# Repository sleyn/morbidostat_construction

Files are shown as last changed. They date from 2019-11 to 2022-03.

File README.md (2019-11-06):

# Morbidostat construction
Building Osterman Lab implementation of morbidostat.

Detailed description of morbidostat components:
1. [Hardware](./Hardware.md)
2. [Software](./Software.md)
3. [Standard operating procedures](./SOP.md)
4. [Spreadsheet with componets specifications](./aux_files/components.xlsx)

## General principles
We constructed our morbidostat based on the same principles that were described in the Toprak et al. paper <a href='#link1'>[1]</a>. In short:  
1)	Optical density of the culture in the reactor is measured every fixed time.  
2)	At the time when the software should initiate dilution the current optical density (OD1) is compared with two values: Upper threshold (UT) and previous optical density (OD0).  
3)	If OD1 ≥ UT and OD1-OD0 ≥ 0 the dilution is made with the drug media.  
4)	Else the fresh media is added

We introduced a new feature - **the lower threshold (LT)**. If OD1 < LT then morbidostat dilutes the culture in the reactor once in hour with the fresh media. LT used:  
1. to allow to start the run on the very low initial OD and to enable active dilution at the same OD for all reactors;  
2. to prevent wash out of the culture during the run.

Dilution by fresh media below the LT once per hour helps to avoid reactor drying during long “sleeping” phase and to decrease residual drug concentration without wash out of the culture.

## Assembled Morbidostat

Morbidostat was assembled in the custom-made box equipped with thermostat, web-camera and air pump.

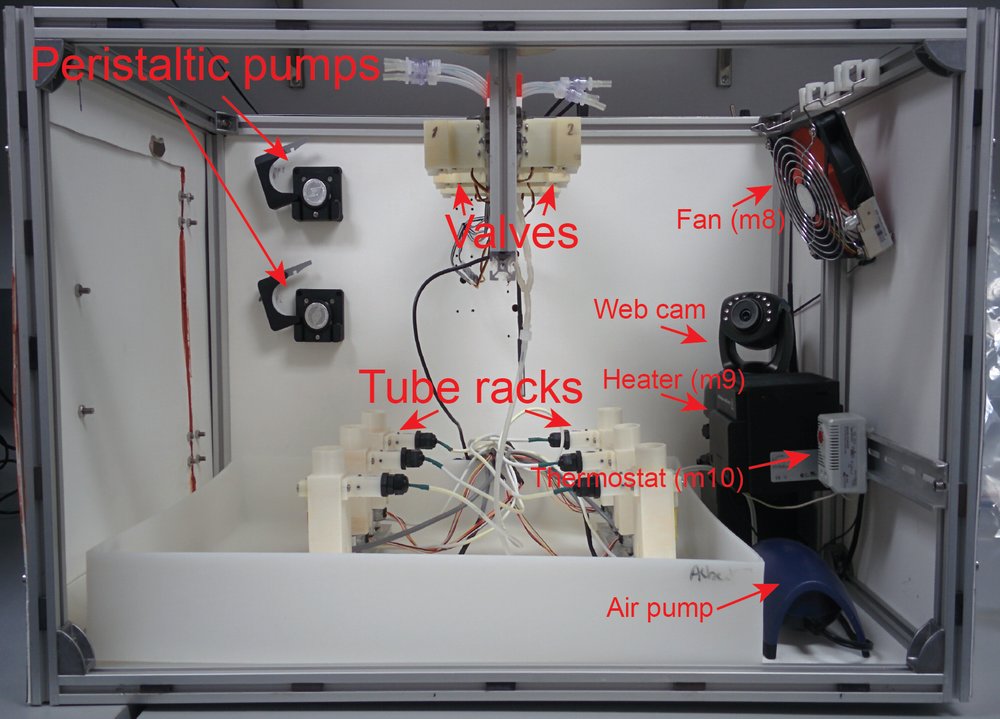
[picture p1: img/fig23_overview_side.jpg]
Morbidostat side
<br>
**Figure 1.** Morbidostat. Side view.

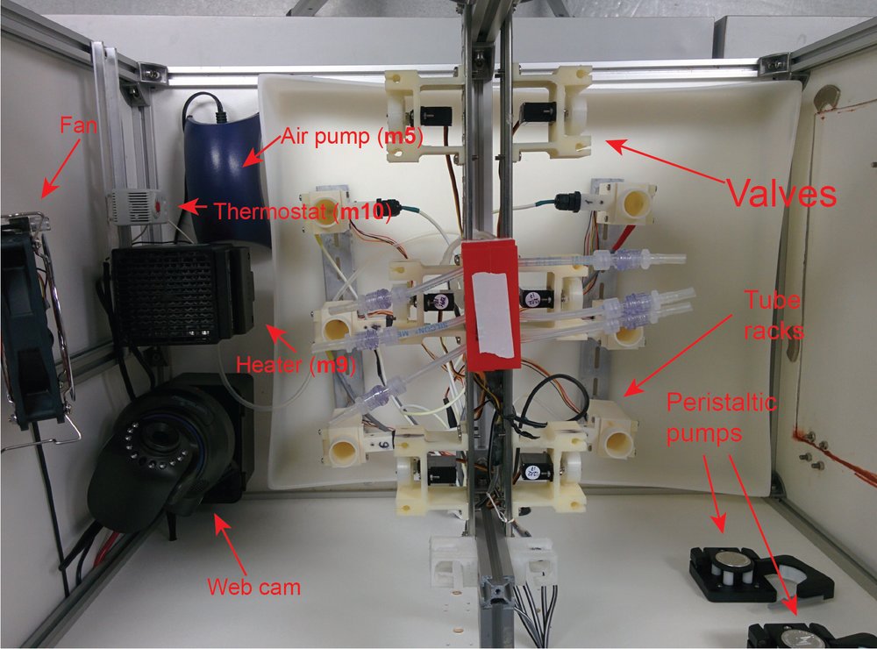
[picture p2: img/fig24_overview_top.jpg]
Morbidostat top
<br>
**Figure 2.** Morbidostat. View form above.

## References

[1]: Toprak E, Veres A, Yildiz S, Pedraza JM, Chait R, Paulsson J, Kishony R: Building a morbidostat: an automated continuous-culture device for studying bacterial drug resistance under dynamically sustained drug inhibition. Nat Protoc 2013, 8(3):555-567.  
DOI: [10.1038/nprot.nprot.2013.021](http://dx.doi.org/10.1038/nprot.nprot.2013.021)

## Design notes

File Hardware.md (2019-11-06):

#### [<Back](./README.md)

# Morbidostat hardware components

- [1. Fluidics](#p1)
  * [1.1 Detailed tubing description](#p11)
    * [1.1.1	Media bottles with the connection lines](#p11)
    * [1.1.2 Distribution lines](#p112)
    * [1.1.3 Reactor tubing and reactor](#p113)
    * [1.1.4 Waste lines](#p114)
- [2. Mechanics](#p2)
  * [2.1 Detailed mechanical parts description](#p21)
- [3. Optics](#p3)
  * [3.1 Detailed optics description](#p31)
- [4. Electrical schemes](#p4)
- [5. 3D-printing](#p5)
  * [5.1 STL files](#p51)
- [6. Assembled morbidostat](#p6)

## 1. Fluidics
Morbidostat has five types of the tubing parts:
1.	**Media bottles with the connection lines** – store drug-containing and fresh media and connect bottles to the pumps.
2.	**Distribution lines** – distribute media among six reactors. Distribution is controlled by peristaltic pumps and valves. Valve simultaneously close or open both tubes containing fresh and drug media. One valve works for one reactor – six valves total. For the dilution the reactors valve opens and one of the pump controlling fresh or drug-containing media start operating.
3.	**Reactor input tubing** – aeration and dilution media introduction. We united air and media input tubings to allow air to make a dry space between fresh media and culturing media. It was made to avoid backflow of the cultured bacteria to the sterile media bottles. This tubing connected to the needle that has its blunt end in the culturing media to introduce bubbling that increases an aeration.
4.	**Reactor** – glass culture tube. Has three ports: input, sampling and waste. In all three ports blunt needles are inserted into the septa. OD in the reactor is measured by laser that is located in the tube rack. To introduce mixing a small stirring motor with the magnets rotates the bar in the tube.
5.	**Waste line** – open line which leads to the bottle with sodium azide. Waste is removed from the reactor by the air pressure. The line has a check valve that prevents backflow of the waste media from the tubing to the reactor.

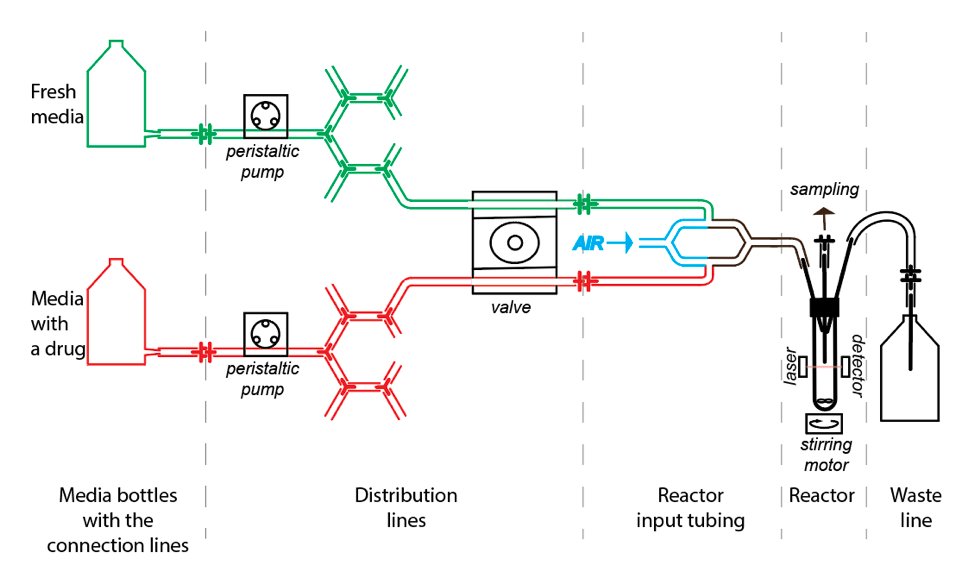
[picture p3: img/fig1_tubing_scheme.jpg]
General scheme of the morbidostat tubing
<br>
**Figure 1.** General scheme of the morbidostat tubing. Tubing colors:  
  *green* – fresh media,  *red* – drug-containing media,  *blue* – air.

### 1.1 Detailed tubing description
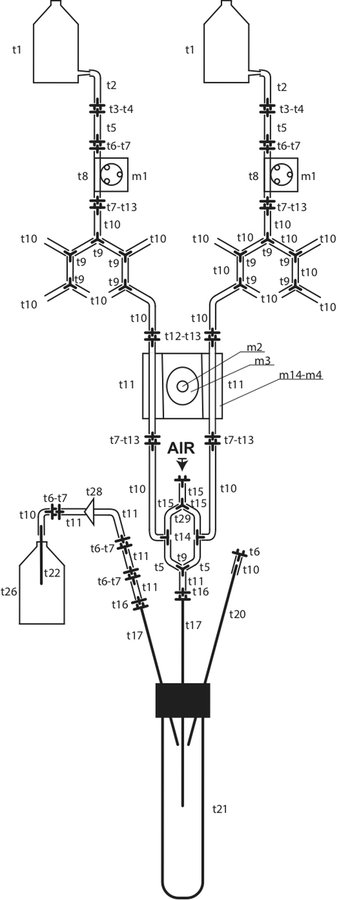
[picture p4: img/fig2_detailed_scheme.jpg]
Detailed tubing scheme
<br>
**Figure 3.** Detailed tubing scheme.  
The part numbers are indicated according the supplementary parts specification table.

#### 1.1.1	Media bottles with the connection lines
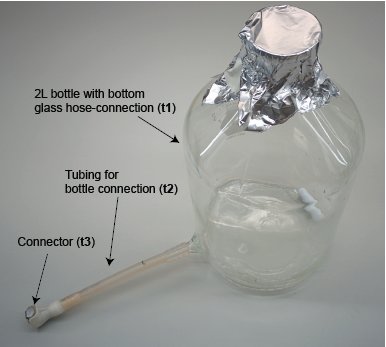
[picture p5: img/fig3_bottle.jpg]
Media bottle
<br>
**Figure 3.** Media bottle with tubing.  
Alpha-numeric parts numbers in parenthesis here and further identify components in the parts specification table.

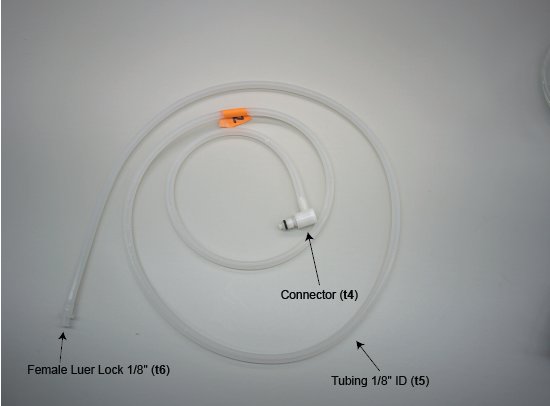
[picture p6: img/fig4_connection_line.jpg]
<br>
**Figure 4.** Connection line.

#### 1.1.2 Distribution lines

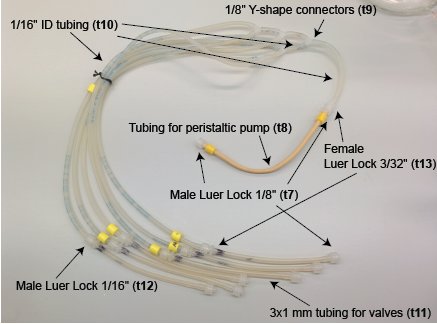
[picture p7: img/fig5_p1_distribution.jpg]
<br>
**Figure 5.** Fresh media distribution line.

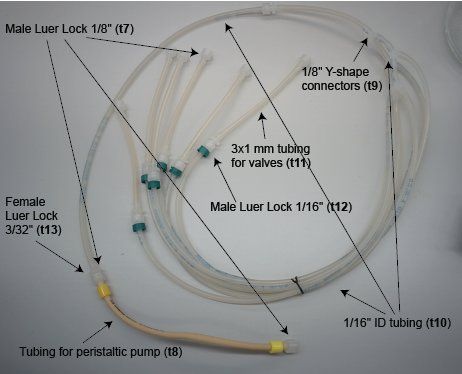
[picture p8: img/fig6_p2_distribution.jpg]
<br>
**Figure 6.** Drug-containing media distribution line. Tubing scheme is the same as for the line on figure 4 but has an additional elongation segment.

#### 1.1.3 Reactor tubing and reactor

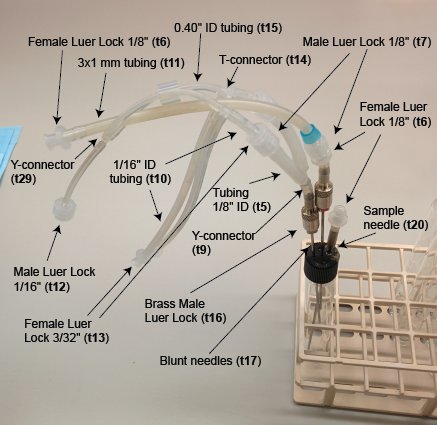
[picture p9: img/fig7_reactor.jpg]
Reactor
<br>
**Figure 7.** Reactor and reactor tubing.

#### 1.1.4 Waste lines

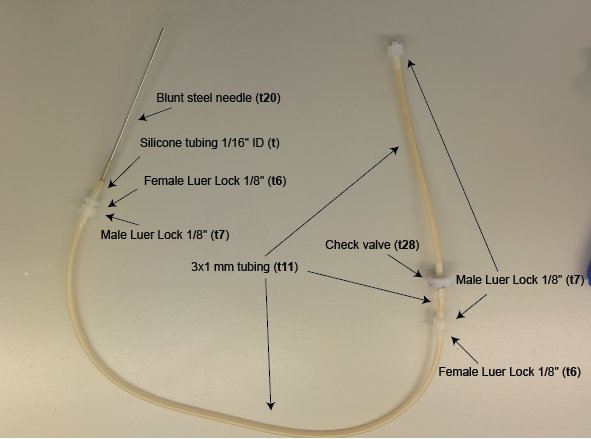
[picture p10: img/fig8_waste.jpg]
Waste line
<br>
**Figure 8.** Waste line.

## 2. Mechanics

Morbidostat contains several mechanical parts:
1. Pinch valves that restrict flow of liquid to desired tube;
2. Two pumps for fresh and drug-containing media;
3. Step motors for stirring magnetic bars in the reactors.

### 2.1 Detailed mechanical parts description

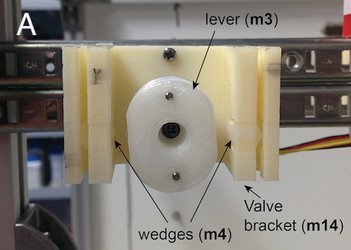
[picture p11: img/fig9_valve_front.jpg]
Valve_A
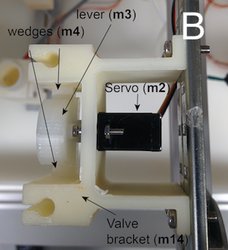
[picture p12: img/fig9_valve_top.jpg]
Valve_B
 <br>
**Figure 9.** Pinch valve for restricting media flow. A – front view; B – top view. Distribution lines are inserted to the channels on the sides. Flow is restricted by servo motors that push wedges that clamp tubing. Bracket, lever and wedges are 3D-printed. The STL files with models could be found in the `3D_printing` folder.

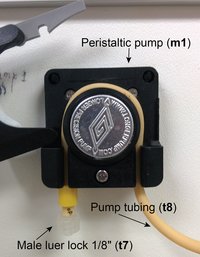
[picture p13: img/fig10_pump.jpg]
Pump
<br>
**Figure 10.** Peristaltic pump for media.

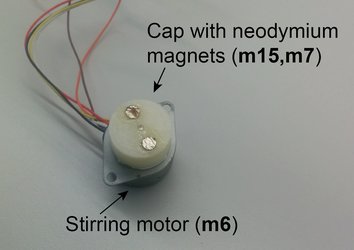
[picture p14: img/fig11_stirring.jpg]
Stirring motor
<br>
**Figure 11.** Stirring motor with neodymium magnets. STL file for the magnets holders could be found in the `3D_printing` folder.

## 3. Optics
Correct work of the morbidostat relies on the reliable OD measurements. For this we measure intensity of the laser beam that goes through the culture. Use of the round culture tubes as the reactors brings a problem of lens effect when laser beam moves aside of the detector.
To prevent this, we are using:  
1. Nylon O-rings to stabilize the reactor at one position;
2. Set screws and nylon gasket to set the laser position. Set screw adjusted to move laser diode inside the gasket and set its position to be aligned with diode when the reactor is set.

To build Photodiode Voltage output to OD calibration curve we are using barium sulfate calibration standards.

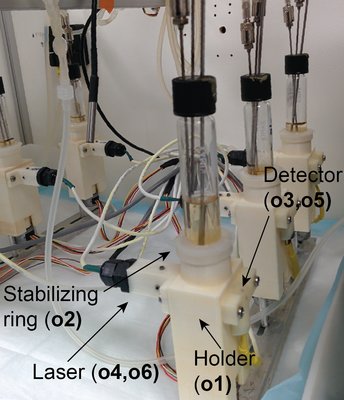
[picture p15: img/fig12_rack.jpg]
Tube holders
<br>
**Figure 12.** Tube holders with lasers and photodetectors installed.

### 3.1 Detailed optics description
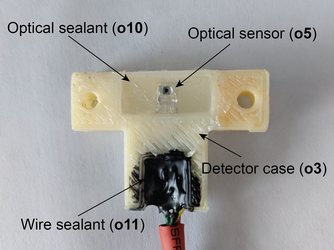
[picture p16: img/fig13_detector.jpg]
Photodetector
<br>
**Figure 13.** Photodetector. STL file for the photodetector case could be found in the `3D_printing` folder.

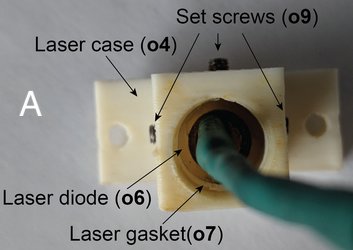
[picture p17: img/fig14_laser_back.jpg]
Laser back
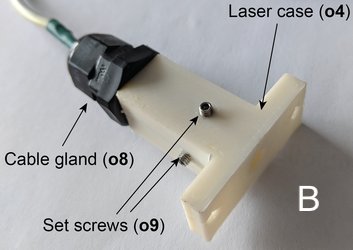
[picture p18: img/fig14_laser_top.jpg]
Laser top
 <br>
**Figure 14.** Laser. A. Back view, B. View from above. STL files for the laser case and gasket could be found in the `3D_printing` folder.

## 4. Electrical schemes

Electric scheme consists of a few main components:
1.	Power supplies
2.	Mega 2560 Arduino control boards
3.	Two custom made wiring boards
4.	Valve servo motors control board
All morbidostat elements and logic except the agitation are controlled by Arduino 1 board. Arduino 2 board controls only stirring motors.

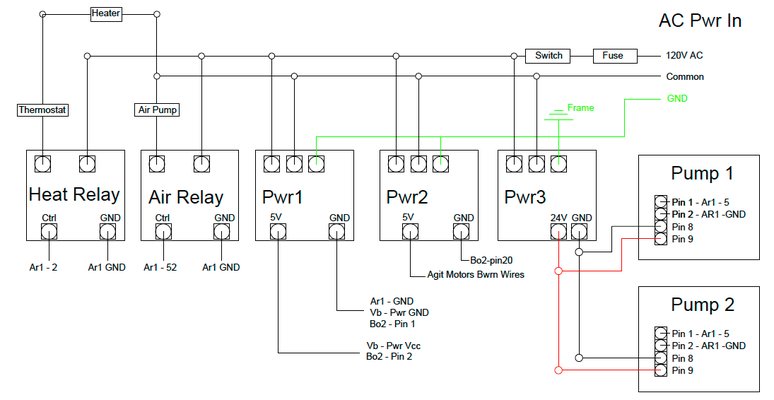
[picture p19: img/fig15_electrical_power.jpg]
Power
<br>
**Figure 15.** Electric power scheme.

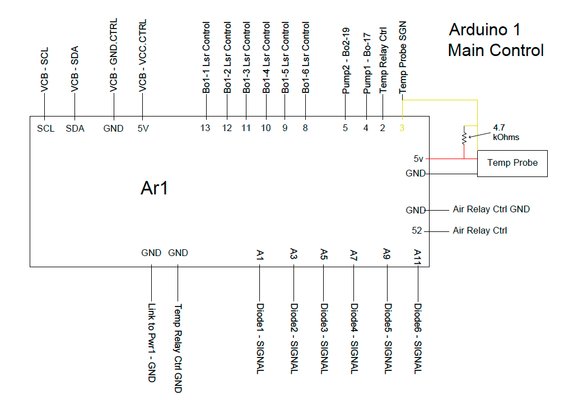
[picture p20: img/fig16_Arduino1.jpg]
Arduino 1
<br>
**Figure 16.** Arduino 1 (main control board) wiring scheme.

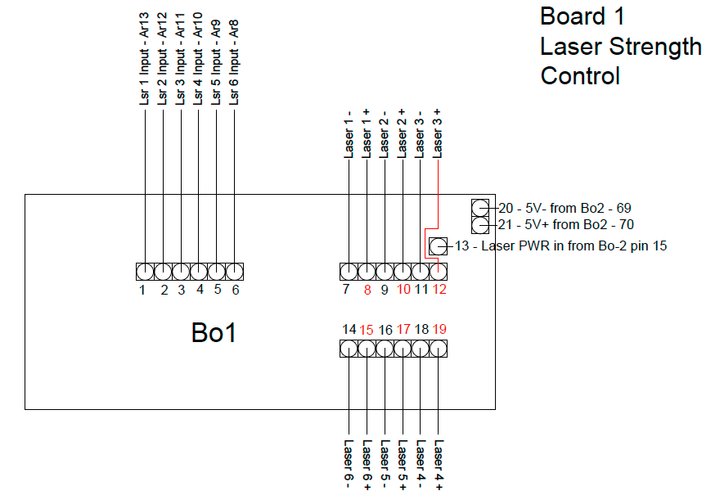
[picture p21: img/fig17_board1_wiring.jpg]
Board1 wiring
<br>
**Figure 17.** Wiring scheme for laser control board 1.

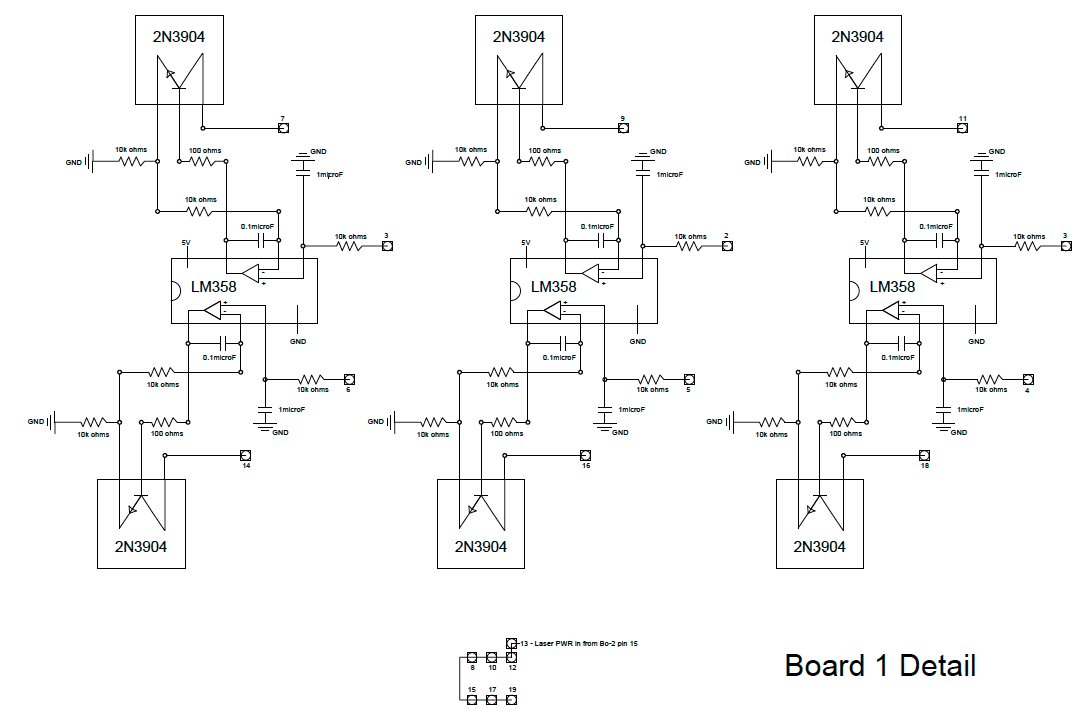
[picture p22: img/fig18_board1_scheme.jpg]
Board1 scheme
<br>
**Figure 18.** Electrical scheme for laser control board 1.

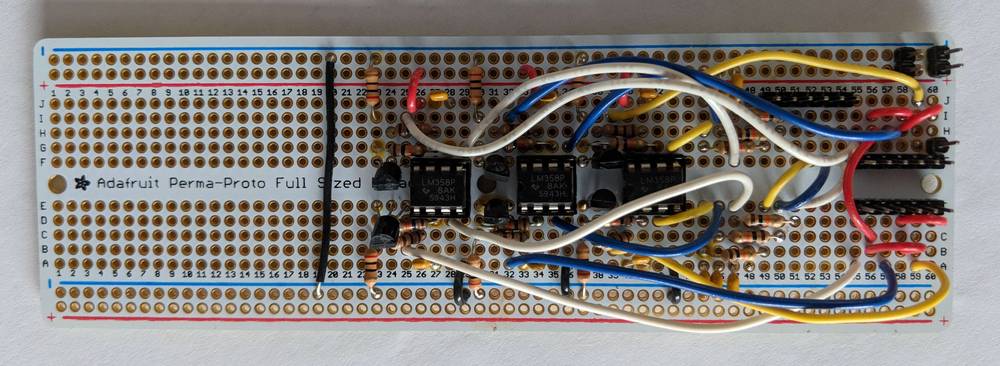
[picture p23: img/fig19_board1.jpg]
Board1
<br>
**Figure 19.** Assembled laser control board 1.

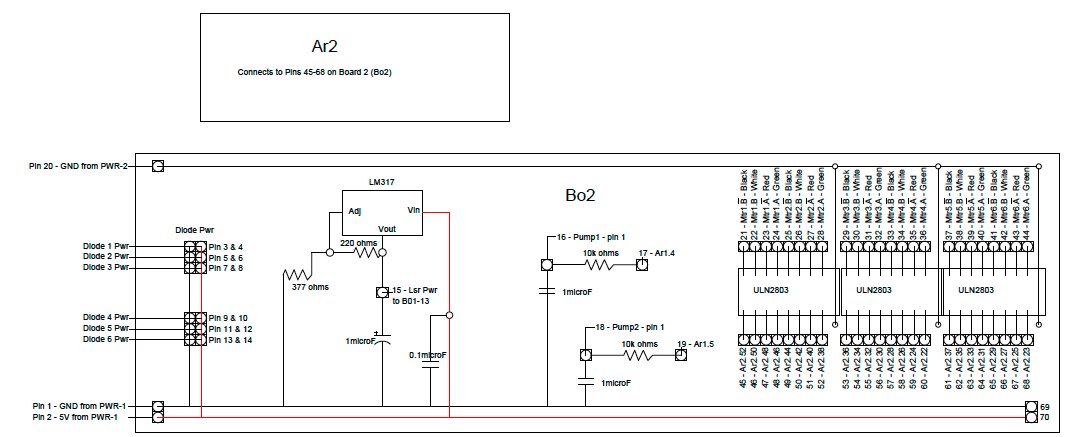
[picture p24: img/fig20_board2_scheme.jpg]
Board2 scheme
<br>
**Figure 20.** Board 2 is responsible for stirring motors control, powering photodetectors and cleaning the pump control signal.

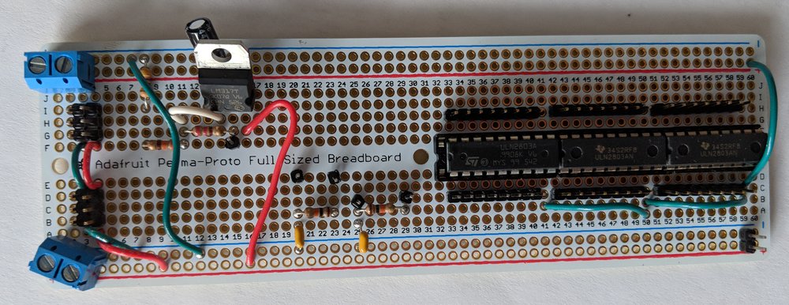
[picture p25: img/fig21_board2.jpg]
Board2
<br>
**Figure 21.** Assembled control board 2.

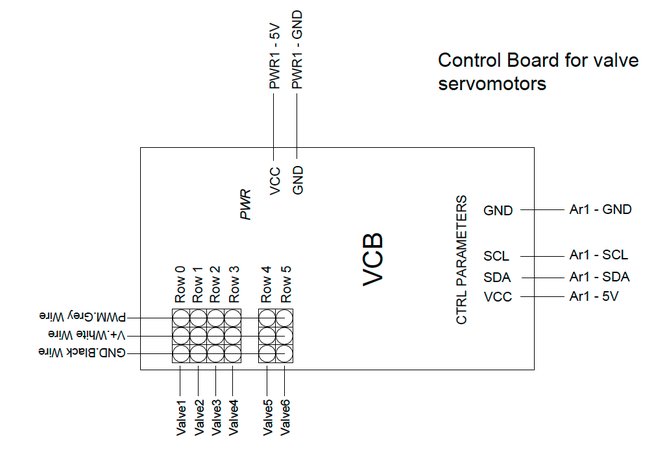
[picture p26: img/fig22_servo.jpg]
Servo wiring
<br>
**Figure 22.** Wiring of the servo motor control board.

## 5. 3D-printing

All 3-D printed parts were made with ABS plastic except for the "O-ring" and “Laser gasket” that were made with bridge nylon

3D Printer used - Lulzbot Taz 5

Water soluble Elmers glue was used on the base of the bed during nylon prints

3D settings1 3D settings2<br>
**Figure 23.** Parameters for 3D printer.

### 5.1 STL files
STL files for printing custom parts for Morbidostat are located in `3D_printing` folder.

- `DiodeMount.stl` - Photodiode case.
- `LaserGasket.stl` - Gasket used for the laser positioning inside the case.
- `LaserHolder.stl` - Laser case.
- `MagnetHolder.stl` - A cap for stepper motors with the places for magnets.
- `TestTubeHolder.stl` - Reactor tube holder.
- `TopTubeGasket.stl` - O-ring for reactor stabilization.
- `Valve.stl` - Valve bracket that holds servo motors and tubing.
- `ValveLever.stl` - Oval lever for servo motors. It pushes wedges that close tubing.
- `ValveWedge.stl` - Wedges for tube closing.

## 6. Assembled morbidostat

Morbidostat was assembled in the custom-made box equipped with thermostat, web-camera and air pump.

Morbidostat side<br>
**Figure 24.** Morbidostat. Side view.

Morbidostat top<br>
**Figure 25.** Morbidostat. View form above.

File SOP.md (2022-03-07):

#### [<Back](./README.md)

# Standard operating procedures

Workflow scheme
**Figure 1.** Morbidostat run procedure scheme.

# Table of contents

- [Calibration](#sop1)
- [Morbidostat assembly](#sop2)
- [Filling of the feed lines](#sop3)
- [Program setup](#sop4)
- [Innoculated tubes installation](#sop5)
- [Start of the run](#sop6)
- [Sampling](#sop7)
- [Processing and storing samples](#sop8)
- [Finish the experiment](#sop9)
- [In-morbidostat washing after a run](#sop10)
- [Disassembling and washing](#sop11)

### Calibration

The goal of calibration is to find **slope (C)** and **intercept (V0)** for equation **OD600 = V0 + C\*log(Voltage)**, where *Voltage* is output from the photosensors and *OD600* is measured Optical Density (with 600nm wavelength) for a calibration standard.

We used BaCl2 suspension as calibration standards.
1.	Prepare:
  -	150 ml 1% H2SO4
  -	5 ml 1% BaCl2
  -	6 culture tubes with screw caps identical with those used for reactors
2.	Prepare 25 ml of standards based on the table:
McFarland

| goal (McFarland) | 1% BaCl2 (uL) | 1% H2SO4 (ml) |
| --- | --- | --- |
| 0.25 | 63 | 24.93 |
| 0.5 | 125 | 24.88 |
| 1 | 250 | 24.75 |
| 2 | 500 | 24.50 |
| 3 | 750 | 24.25 |
| 4 | 1000 | 24.00 |

3.	Vortex standards vigorously.
4.	Take aliquots of standards to check McFarland and OD600 values on the McFarland densitometer and spectrophotometer.
5.	Mark true values on the upper part of the tubes.
6.	Set C=1 and V0=0.
7.  Measure values on warmed morbidostat and make linear regression TrueValue (Od or MF) ~ (Mesurement). The R^2 should be more then 0.97.
8.  Type values in the Calibration tab of Software.

### Morbidostat assembly

1. Check if all valves are open. If not – rotate step motors into the open position.
2. Check if all wedges are open and allow free installation of the tubing into the valves. If not – use any thin instrument to move them (like a paper clip).
3.	Install pump 1 distribution line in the peristaltic pump. Don’t close the peristaltic pump.
4.	Install pump 1 distribution line in the valves.
5.	Do the same for the pump 2.
6.	Connect media connection lines. Pull peristaltic pump tubing to the position when stopper touch the pump case.
7.	Close peristaltic pumps.
8.	Install new air filters to the air entrance of the reactor cap tubing.
9.	Install reactors in the rack.
10.	Connect tubing, media distribution lines and air lines.
11.	Connect media bottles to the media connection lines.
12.	Add 20 ml of 5% sodium azide to the waste bottles.
13.	Connect waste lines to the reactors.
14.	Connect waste lines to the waste bottles.
15.	Turn on Morbidostat.

### Filling of the feed lines
First fill line with a Pump 2 media (with a drug). Then Fill line with Pump 1 media and wash feed needle with no drug media.

1.	On the Connection Manager tab connect to the Morbidostat.
2.	On the Settings tab do check/un-check for all valves to be sure that valves are closed.
3.	On the same tab open valve 1 by checking corresponding On/Off check-box.
4.	On the same tab  start pump 2 by checking Pump 2 On/Off check-box.
5.	Stop Pump 2 manually by un-checking Pump 2 On/Off check-box after media will fill the tubing.
6.	Close valve by un-checking corresponding On/Off check-box
7.	Repeat 3-6 for other reactors.
8.	In the Morbidostat Software on the Control tab check all tubes that are in experiment.
9.	On the Settings tab set for all reactors:
  -	Cycle time = 2 min
  -	Dilution time = 16 s
  -	Air pump = checked (On)
  -	Air Delay = -1 (No turning off of Air during pumping)
  -	For Cleaning = Pump1
10.	On the Control tab turn on OD Reading and Automatic Dilution.
11.	Wait for 2 washing cycles and click on Off button for Automatic Dilution and OD Reading at the end of the second cycle.

### Program setup

1.	On the Connection Manager tab connect to the Morbidostat and Agitation boards.
2.	On the Control tab:
  -	Check all tubes that are in the experiment.
  -	Set temperature (Standard = 37°C).
  -	While waiting for inoculated tubes turn on Temperature Control to warm optics.
3.	On the Settings tab:
  -	Set Lower Dilution thresholds (Standard = 0.15. Will be adjusted on the start).
  -	Set Upper Dilution thresholds (Standard = 0.3. Will be adjusted on the start).
  -	Cycle time (in minutes) (Standard = 15).
  -	Dilution time (in seconds) (Standard = 16 sec). 1sec = 0.3ml of added media.
  -	Laser strength should be the same as it was during calibration.
  -	Air Delay (Standard = 5 sec).
  -	Set For Cleaning = None.
4.	On the Message Logger tabs set log files for OD and Pump logs. Be sure that in the time settings menu “Include date” and “Include time” are checked.
5.  Close all lids.

### Innoculated tubes installation

1.	Put O-rings on the inoculated tubes.
2.	Open all morbidostat lids.
3.	Start from distant tubes. Rotate a reactor tube (NOT a cap) to unscrew it.
4.	Take off a cap. Be sure that needles do not touch anything. If necessary lift needles.
5.	Replace tube with inoculated one.
6.	Screw tube by rotating it (NOT a cap).
7.	Seal the O-ring on the rack and check that tube is touching the bottom of the rack.
8.	Repeat steps 4-7 for all reactors.
9.	Slightly burn all upper parts of the needles with a burner.
10.	Adjust needles:
  -	Set waste needle ~2 mm above the liquid surface.
  -	Set input needle tip under the surface ~15 mm lower than waste needle.
  -	Set sample needle above laser. Tip: Top of sample needle should be ~20mm above a top of the waste needle.
11.	Close all lids.

### Start of the run

1.	On the Control tab turn on:
  -	OD Reading
  -	Temperature Control (if it was not already turned on)
2.	On the Settings tab turn on:
  -	Air.
3.	On the Agitation tab turn on:
  -	Agitation.
4.	Wait ~20 min to warm optics.
5.	Get current OD from the Optical Density plot and count it as zero OD.
6.	On the Settings tab adjust Lower Dilution and Upper Dilution thresholds by adding current OD.
7.	**IMPORTANT:** Turn on logging for OD and pumps on the Message Logger tabs.
8.	On the Control tab turn on:
  -	Automatic Dilutions
9.	Visually check system integrity (air bubbling, liquid levels, OD plots, temperature) after first dilution.

### Sampling

1.	Have ready sterile Pump 1 media for dilution at 37°C
2.	Prepare 6x15 mL falcons marked with sample names (containing reactor number and time point ID), 10 mL syringes
3.	Stop air, OD reading, dilution on software tab
4.	Take samples, one by one, from each reactor:
  -	Flame and lower the sampling needle; aspirate 10 mL in syringe, dispense to respective 15 mL tube;
  -	Take 10 mL Pump 1 media, inject into the same port
  -	Leave syringe in place, lift the needle, tape over the syringe (to avoid displacement)
  -	Repeat for all reactors that you want to sample
5.	Check all levels, turn on air, check bubbling
6.	Close box, turn on reading, check values;
7.	If OK, turn on dilution.

###	Processing and storing samples

1.	Glycerol stocks:
  -	Prepare 6 sterile Eppendorf tubes, dispense 300 µL of 50% glycerol each
  -	To each – add 600 µL from each sample, mark on top 1B, 2B…. 6B or whatever letter   corresponding to sampling cycle.
  -	Mix, spin down, freeze in liquid N2, put in -80 box
2.	Cell pellets (for genomic DNA):
  -	Spin remaining samples (~ 9.4 mL) in Beckman: RPM=4,000; Time = 7 min; Temp= 10°C
  -	Remove supernatant: pour off the majority and use 1 mL pipettor to aspirate remainder   (alternatively use vacuum aspiration)
  -	Resuspend each pellet in 10 mL saline: Resuspend using 1 mL pipette to pull sample up   and down until uniform and no chunks are present (vortex is much less effective)
  -	Spin again, same parameters
  -	Remove supernatant, resuspend in 5 mL each (washing step, optional)
  -	Variation – make one or two duplicate aliquots.  
  -	Spin, resuspend by pipette in 1.5 mL (for one aliquot);  [option -   in 3 mL (to split between two tubes, depends on the number of cells and importance)]
  -	Transfer to color-coded (by cycle) 2 mL Eppendorf, label on top
  -	Spin in microcentrifuge (5 min, 14,000)
  -	Remove super, freeze pellets in in liquid N2, put in -80 box

###	Finish the experiment

1.	On the Settings tab turn off:
  -	Air
2.	On the Control tab turn off:
  -	OD Reading
  -	Automatic Dilutions
  -	Temperature Control
3.	Take last samples (Look in the sampling protocol).
4.	On the Agitation turn off:
  -	Agitation

###	In-morbidostat washing after a run

1.	Prepare
  -	~300 ml of 10% bleach in a bottle.
  -	~300 ml of 20% ethanol in a bottle.
  -	Two tubing ~30 cm with female luer connectors
2.	Disconnect media bottles, save residual media if needed and bring it for washing.
3.	Disconnect media connection tubing part before both peristaltic pumps.
4.	Connect the bottle with the fresh bleach to both peristaltic pumps with any tubing. Close all morbidostat lids to decrease bleach odor.
5.	In the Morbidostat Software on the Settings tab set for all reactors:
  -	Cycle time = 2 min
  -	Dilution time = 16 s
  -	Air pump = checked (On)
  -	Air Delay = -1 (No turning off of Air during pumping)
  -	For Cleaning = Pump1
6.	In the Morbidostat Software on the Control tab check all the tubes and set:
  -	OD Reading = ON
  -	Automatic Dilutions = ON
7.	Wait 5 minutes.
8.	Set Automatic Dilutions = OFF. Wait until program is finished (The green indicator near Automatic Dilution become blank).
9.	In the Morbidostat Software on the Settings tab set For Cleaning = Pump2
10.	Redo steps 6-8.
11.	Wait 10 minutes.
12.	Switch the bleach bottle with the ethanol bottle.
13.	Redo steps 5-11.
14.	Disconnect ethanol bottle and leave pumps tubing disconnected.
15.	Redo steps 5-11 to empty feed lines.
16.	Turn off OD reading and Air in the Software and then turn off Morbidostat power switch.

###	Disassembling and washing

1.	Prepare:
  -	The plastic tray.
  -	50ml falcon with 10% bleach (Use the leftovers from the bleach bottle).
  -	Magnetic stick retriever.
  -	Culture tube holder.
2.	Disassemble waste lines from reactors. Rinse waste lines needles in the bleach. Put them in the tray.
3.	Disconnect all feed distribution lines and air line. Discard air filters.
4.	One by one for each reactor:
  -	Unscrew reactor caps and put it in the tray.
  -	Pour out all liquid from the tube. With the help of the magnetic stick retrieve  - keep stirring bar inside the tube while pouring.
  -	Put the tube on the holder.
5.	Put the tray under feed lines ends.
6.	Open all valves.
7.	Pull out all tubing out of valve holders and put them in the tray.
8.	Open peristaltic pumps.
9.	Pull out the tubing out of the peristaltic pump.
10.	Bring tubing and tubes for washing.
11.	Bring waste bottles to the hood.
12.	Pour bleach to waste bottles in a volume about 10% of waste.
13.	Close Waste bottles to minimize an odor.
14.	Let waste stay for ~30 min.
15.	Pour out waste.
16.	Bring waste bottles to the washing.
17.	Wash everything with soap water and laboratory brush. Then rinse thoroughly with DI-water.
18.	Let everything dry. Water from tubing could be sucked with vacuum.
19.	Assemble reactors and close sample needle with a stopper.
20.	Foil all open connectors and pack everything for autoclaving. **NOTE:** Don’t forget to put stirring bars to reactors and media bottles prior to autoclaving.
21.	Autoclave 30 min on the gravity cycle.

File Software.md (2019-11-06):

#### [<Back](./README.md)

# Software
The morbidostat control logic implemented on the Arduino programming language. GUI is designed with the [MegunoLink](https://www.megunolink.com/) interface tool.

Main principles of morbidostat logic are described in the  Toprak et al paper <a href='#link1'>[1]</a>.

Code could be found in the `software/v4.2` folder
- `MorbidostatGUI4.2.mlx` - MegunoLink GUI Interface
- `morbidostat2-7-18` - Arduino 1 code (main controls)
- `motorcontrol` - Arduino 2 code (stepper motors control)

## Graphical User Interface
GUI provides an interface to exchange information with Arduino board.

Interface has 3 major sections:
1.	 Connection controls/Logs outputs controls
2.	 Run controls
3.	 Real-time plots/logs from the current run.

Software main

### 1. Connection controls/Logs outputs controls
In this part you can control general connection of computer to the morbidostat logic boards and set output log files.

- **Connection manager**

Connection manager

- **Message logger**

Message logger

### 2. Run controls
In this section you can control morbidostat process (turn on/of OD reading, media pumps, heater, air pump) and set parameters for the run (thresholds, dilution rates, temperature in the chamber, select tubes that are used in the experiment).

- **Control tab**

Control tab

- **Settings tab**

Settings tab

- **Agitation tab**

Agitation tab

- **Calibration**

Calibration tab

### 3. Real-time plots/logs from the current run
Sections shows OD plot and log of pumps activations.

- **OD plot**

OD plot

- **Pump engagement log**

!Pump log

## References

[1]: Toprak E, Veres A, Yildiz S, Pedraza JM, Chait R, Paulsson J, Kishony R: Building a morbidostat: an automated continuous-culture device for studying bacterial drug resistance under dynamically sustained drug inhibition. Nat Protoc 2013, 8(3):555-567.  
DOI: [10.1038/nprot.nprot.2013.021](http://dx.doi.org/10.1038/nprot.nprot.2013.021)

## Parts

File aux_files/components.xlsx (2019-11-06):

Internal Part code | Category | Name | Description | Part number | Source | Site | Price ($, approximate)
t1 | Tubing | KIMAX KIMBLE 2000ml | 2L bottle with bottom glass hose-connection | 14607-2000 | Kimble | https://www.fishersci.com/shop/products/kimax-aspirator-bottles-tubulation-7/p-47957 | 162
t2 | Tubing | Silcon Medical Silicone Tubing 3/16 ID x 3/8 OD x 1' | Tubing for bottle connection | 281-0306 | Silcon | https://www.freshwatersystems.com/p-9025-silcon-medical-silicone-tubing-316-id-x-38-od-x-1.aspx | 41 per 25 feet
t3 | Tubing | Valved In-Line Hose Barb Coupling Body 3/16 ID Barb | Female connector | PMCD1703 | Colder | https://www.freshwatersystems.com/p-7990-pmc-valved-in-line-hose-barb-coupling-body-316-id-barb.aspx | 5.72
t4 | Tubing | Valved Elbow Hose Barb Coupling Insert 1/8 ID Barb | Male Connector | PMCD2302 | Colder | https://www.freshwatersystems.com/p-7984-pmc-valved-elbow-hose-barb-coupling-insert-18-id-barb.aspx | 7.27
t5 | Tubing | Silcon Silicone Tubing 1/8 ID x 1/4 OD x 1' | Tubing for bottle connection | 280-0204 | Silcon | https://www.freshwatersystems.com/p-9001-silcon-silicone-tubing-18-id-x-14-od-x-1.aspx | 13 per 25 feet
t6 | Tubing | Nordson Medical FEMALE LUER THRD LOCK 100/PK | Female Luer Thread Style to 200 Series Barb 1/8" (3.2 mm) ID Tubing Animal-Free Natural Polypropylene | NC1263828 (Nordson Medical FTLL2306005) | Nordson Medical | https://www.fishersci.com/shop/products/female-luer-thrd-lock-100-pk/nc1263828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 | 31.30 per 100 pack
t7 | Tubing | Nordson Medical MALE LUER INTEG LOCK RING 100P | Male Luer Integral Lock Ring to 200 Series Barb 1/8" (3.2 mm) ID Tubing Animal-Free Natural Polypropylene | NC1279310 (Nordson Medical MTLL2306005PK) | Nordson Medical | https://www.fishersci.com/shop/products/male-luer-integ-lock-ring-100p-1/nc1279310#?keyword=mtll230 | 34.45 per 100 pack
t8 | Tubing | Pump Tubing Kit #7318249 | Pkg of 1, 3.2 mm ID PharMed, pump tubing kit, 20 precut lengths and 4 sets of fittings | 7318249 | Bio-Rad | http://www.bio-rad.com/en-us/sku/7318249-pump-tubing-kit | 132
t9 | Tubing | Nordson Medical CONNECTOR, Y BARB 1/8 | Y Tube Fitting with 200 Series Barbs 1/8" (3.2 mm) ID Tubing Animal-Free Natural Polypropylene | NC0438025 (Nordson Medical Y2306005) | Nordson Medical | https://www.fishersci.com/shop/products/connector-y-barb-1-8/nc0438025#?keyword=Y230 | 45.86 per 100 pack
t10 | Tubing | Silcon Medical Silicone Tubing 1/16 ID x 3/16 OD x 1' | Main media distribution system | 281-0103 | Silcon | https://www.freshwatersystems.com/p-9023-silcon-medical-silicone-tubing-116-id-x-316-od-x-1.aspx | 37.50 per 50 feet
t11 | Tubing | Micro Flow ( WX10-14 & DG Series) 3x1 tubing | Tubing for valves | 3x1 tubing | Langer Instruments | http://langerinstruments.com/microflowwx1014dgseries-p-20.html | 55 per 50 feet
t12 | Tubing | Nordson Medical MALE LUER INTEGRAL LOCK | Male Luer Integral Lock Ring to 200 Series Barb 1/16" (1.6 mm) ID Tubing Natural Kynar PVDF | NC0282318 (Nordson Medical MTLL210J1A) | Nordson Medical | https://www.fishersci.com/shop/products/male-luer-integral-lock-8/nc0282318#?keyword=mtll210 | 50.55 per 100 pack
t13 | Tubing | Nordson Medical FEMALE LUER INTEGRAL LOCK | Female Luer Thread Style to 200 Series Barb, 3/32" (2.4 mm) ID Tubing, Animal-Free Natural Polypropylene | FTLL220-6005 | Nordson Medical | http://www.nordsonmedical.com/search/search.aspx?p=FTLL220 | 18.80 per 100 pack
t14 | Tubing | 1/16" T Type Polypropylene Connector | 1/16" T Type Polypropylene Connector | 64028 | Ark-Plas (by United States Plastic Corporation®) | https://www.usplastic.com/catalog/item.aspx?itemid=30634 | 30 per 100 pack
t15 | Tubing | Rinsing Tubing | 0.04" ID tubing | 18-1032-11 | Pharmacia | https://gmi-inc.com/rinsing-tubing-pharmacia-18-1032-11.html | 89 per 2m
t16 | Tubing | Silver Plated Brass Luer Lock Barb Adapter, Small 1 Barb (.150" dia ref) Size | Male luer lock on the needles | 30WJ87 | GRAINGER | https://www.grainger.com/product/GRAINGER-APPROVED-Silver-Plated-Brass-Luer-Lock-30WJ87 | 4.8
t17 | Tubing | 16 gauge, Metal Hub NDL, custom length | point 3, 4" | 7748-02 | Hamilton | https://www.hamiltoncompany.com/products/syringes-and-needles/needle-builder-tool/16-gauge-Metal-Hub-NDL-custom-length-0375-to-12-in-point-style-2-3-or-4-6PK | 48
t18 | Tubing | Sartorius™ Minisart™ High Flow Syringe Filters: Sterile | Dual luer lock non-autoclavable air filters | 14-555-264 | Sartorius | https://www.fishersci.com/shop/products/sartorius-minisart-hf-syringe-filters-sterile-6/14555264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 | 178.50 per 50 pack
t20 | Tubing | Sample needle 7" | 14 gauge steel needle (manually cut) | - | - | - | -
t21 | Tubing | Kimble™ KIMAX™ Reusable Tubes with Rubber-Lined Screw Cap | Reactors. 3 holes should be drilled in the cap. | 14-930D (Kimble™ 45066-20150) | Kimble | https://www.fishersci.com/shop/products/kimax-reusable-tubes-rubber-lined-screw-cap-9/14930d | 252.54 per 48 pack
t23 | Tubing | 3/16" Polypropylene Standard Check Valve with Viton™ Diaphragm | Waste check valves | 64047 | Ark-Plas (by United States Plastic Corporation®) | https://www.usplastic.com/catalog/item.aspx?itemid=32231 | 0.73
t24 | Tubing | Cole-Parmer One-way luer check valve, SAN with silicone diaphragm, female-male, pack of 10 | Air check valves | 30505-92 | Cole-Parmer | https://www.coleparmer.com/i/cole-parmer-one-way-luer-check-valve-san-with-silicone-diaphragm-female-male-pack-of-10/3050592 | 9.10 per 10 pack
t25 | Tubing | GL45 screw cap with holes or insert with ports | Bottle screw cap with three port insert | - | - | - | -
t26 | Tubing | PYREX™ Reusable Media Storage Bottles | Waste bottle | 13952L | Pyrex | https://www.fishersci.com/shop/products/pyrex-reusable-media-storage-bottles-12/p-42752 | 61.93
t27 | Tubing | Septa, tan PTFE/silicone | Septa for reactor caps. tan PTFE/silicone, diam. × thickness 16 mm × 0.060 in., for use with 15 mL vial, pkg of 100 ea | 27380-U | SUPELCO | https://www.sigmaaldrich.com/catalog/product/supelco/27380u?lang=en&region=US | 66 per 100 pack
t28 | Tubing | Fisherbrand™ Chemical-Resistant Check Valves | Check valves for waste lines | 15-078-208 | Fisherbrand | https://www.fishersci.com/shop/products/fisher-scientific-chemical-resistant-check-valves-4/15078208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 | 48 per 6 pack
t29 | Tubing | 1/16" Hose Barb Natural Polypropylene Y Fitting | 1/16" Hose Barb Natural Polypropylene Y Fitting | 65356 | Ark-Plas (by United States Plastic Corporation®) | https://www.usplastic.com/catalog/item.aspx?itemid=90382 | -
m1 | Mechanics | T60&WX10 Series OEM Peristaltic Pump | Peristaltic pumps for media | T60-S2&WX10-14 | Longer Precision Pump Co., Ltd | http://longerpump.com/index.php/OEMwithdirve/show/58.html | 190
m2 | Mechanics | Hitec HS-65Hb Micro Servo Karbonite Gear HRC33065S | Valve motors | HRC33065S | Hitec | https://www.rcplanet.com/radio-system/servos-car-boat/hitec-hs-65hb-micro-servo-karbonite-gear-hrc33065s | 32.95
m3 | Mechanics | Oval valve lever | 3D printed | - | - | - | -
m4 | Mechanics | Wedge | 3D printed | - | - | - | -
m5 | Mechanics | Tetra Whisper Air Pump 40 | Air pump | 77846-00 | Tetra | https://www.amazon.com/Tetra-77853-Whisper-Pump-40-Gallon/dp/B0009YF4FI?th=1 | 10.78
m6 | Mechanics | 4-Phase 5VDC Unipolar Stepper Motor | Stepper motor for agitation | 237825 | Jameco Reliapro | https://www.jameco.com/z/25BY4801-4-Phase-5VDC-Unipolar-Stepper-Motor_237825.html | 9.95
m15 | Mechanics | Magnet cap for the stepper motor | 3D printed | - | - | - | -
m7 | Mechanics | Neodymium magnets | 3/16" dia by 1/8" height round magnets | D32-N52 | K&J Magnetics | https://www.kjmagnetics.com/proddetail.asp?prod=D32-N52 | 0.29
m8 | Mechanics | Thermaltake Mobile Fan 12 External USB Cooling Fan 120mm AF0007 |  | AF0007 | Thermaltake | https://www.amazon.com/gp/product/B002OJN250/ref=oh_aui_detailpage_o00_s00?ie=UTF8&psc=1 | 12.36
m9 | Mechanics | Heater, Touch Safe PTC Fan, DIN Clip, 120 V, 250 W, 90 mm, 85 mm, 111 mm, 3.54 " | Heater | 02811.9-00 | STEGO | http://www.newark.com/stego/02811-9-00/fan-heater-250w-49-to-158-deg/dp/12R2470 | 152
m10 | Mechanics | Thermostat, 0°C to +60°C, Normally Closed, 10 A at 250 Vac, DIN Rail | Thermal regulator | 01146.9-00 | STEGO | http://www.newark.com/stego/01146-9-00/thermostat-controller-nc-ip20/dp/02P6315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 | 34.61
m11 | Mechanics | Color squid | Magnetic stirrer for media bottles | 3671000 | IKA | https://www.ika.com/laboratory-equipment/products/magnetic-stirrers/products/1782/color-squid-white | 377
m12 | Mechanics | Fisherbrand™ Fisherbrand™ Octagon Spinbar™ Magnetic Stirring Bars | Stir bars for media bottles | 14-513-52 | Fisherbrand | https://www.fishersci.com/shop/products/fisherbrand-octagonal-magnetic-stir-bars-12/1451352?searchHijack=true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 | 9.5
m13 | Mechanics | Stir Bar, Magnetic, "X" Shaped, PTFE, 10 x 5: Diameter x Height (mm) | Stir bars for reactors | CG-2013-01 | Chemglass Life Sciences | https://chemglass.com/stir-bars-magnetic-ptfe-x-shaped | 3.55
m14 | Mechanics | Valve bracket (step motor and tubing holder) | 3D printed | - | - | - | -
Arduino 1/Arduino 2 | Electrical | Arduino Mega 2560 Revision 3 | Control logic board | A000067 | ARDUINO | https://www.jameco.com/z/A000067-Arduino-Arduino-Mega-2560-Revision-3_2152366.html?CID=GOOG | 38.49
VCB | Electrical | SunFounder PCA9685 16 Channel 12 Bit PWM Servo Driver for Arduino and Raspberry Pi | Valves motors control | B014KTSMLA | SunFounder | https://www.amazon.com/dp/B014KTSMLA?creative=395033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 | 11.99
Temp Probe | Electrical | Waterproof DS18B20 Digital temperature sensor | Themperature sensor | 381 | adafruit | https://www.adafruit.com/product/381 | 9.95
Pwr1/Pwr2 | Electrical | 5volt 3A Watt Pwr Supply | Powers all 5V DC needs other than agitation | 1919043 | Jameco | https://www.jameco.com/webapp/wcs/stores/servlet/ProductDisplay?productId=1919043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 | 7.4
Pwr3 | Electrical | 24volt 25 Watt Pwr Supply | Powers peristaltic pumps | 2104161 | Jameco | https://www.jameco.com/webapp/wcs/stores/servlet/ProductDisplay?productId=2104161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 | 11.95
Air Relay/Heat Relay | Electrical | Solid State A/C relay 3A | Turns off air pump before dilution for better mixing | SAI4003D | MPJA | https://www.aliexpress.com/item/Freeshipping-PCB-small-solid-state-relay-single-in-line-SAI4003D-DC-to-AC-3A-SSR-input/1552511836.html | 26.77
Bridge Nylon | 3D-Printing | LulzBot Taulman Bridge Nylon 3D Printer Filament, 1 lb. Reel, 3 mm, Natural | Nylon for O-ring (o-2) printing | 817752014939 | LulzBot | https://www.amazon.com/dp/B00ZKDMXE8/ref=psdc_6066128011_t4_B00W6GZ07O | 26.4
ABS | 3D-Printing | LulzBot ABS 3D Printer Filament, 3 mm Diameter, 1 kg Spool, White | ABS plastic for 3D printing | 817752013185 | LulzBot | https://www.amazon.com/LulzBot-Printer-Filament-Diameter-Spool/dp/B00U3L9D2W | 42.95
Glue | 3D-Printing | Washable School Glue, 5 oz, Liquid | Glue for the base of the nylon prints | Elmer's Products-E305 | Elmer's | https://www.amazon.com/Elmers-Washable-School-Glue-Liquid/dp/B004E2ME4U?s=industrial | 5.08
o1 | Optics | Tube holder | 3D printed (testtubeholder.stl) | - | - | - | -
o2 | Optics | O-ring for tube stabilization | 3D printed (toptubegasketshort.stl) | - | - | - | -
o3 | Optics | Detector case | 3D printed (diode mount.stl) | - | - | - | -
o4 | Optics | Laser case | 3D printed (laserholder8-22-16.stl) | - | - | - | -
o5 | Optics | ams TSL14-S-LF-ND | Optical Sensor Ambient 640nm Voltage 3-SMD | TSL14-S-LF-ND | ams | https://www.digikey.com/product-detail/en/ams/TSL14S-LF/TSL14-S-LF-ND/3095037 | 2.35
o6 | Optics | Laser Diode | 5pcs 635nm 638nm 3mW 3V Orange-Red Dot Laser Diode Module <5mW 6x10mm | 635MD-3-0610-5pcs-LM | Laser-Makers | https://www.amazon.com/635nm-638nm-Orange-Red-Module-6x10mm/dp/B075DV1B9M/ | 17.50 per 5 pack
o7 | Optics | Laser gasket | 3D printed (LaserGasket.stl) | - | - | - | -
o8 | Optics | Cable gland | M12 cable glands | AIO-CSM12-ND | Digikey | https://www.digikey.com/product-detail/en/amphenol-industrial-operations/AIO-CSM12/AIO-CSM12-ND/3904956 | 1.38
o9 | Optics | Set screws | M3 X6mm, Fine tuning of laser position | 8707 | Bolt Depot | https://www.boltdepot.com/Product-Details.aspx?product=8707 | 5.84 per 100 pack
o10 | Optics | Optical sealant | Used to fill the photodiode crevice | 908570 | Lowe's | https://www.lowes.com/pd/LOCTITE-Multipurpose-Adhesive/3454788 | 4.28
o11 | Optics | Diode wire sealant | Cover for exposed wires after soldering of photodiode | LTB-400 | Lowe's | https://www.lowes.com/pd/Gardner-Bender-1-in-x-1-ft-General-Duty-Electrical-Tape/3385480 | 6.98

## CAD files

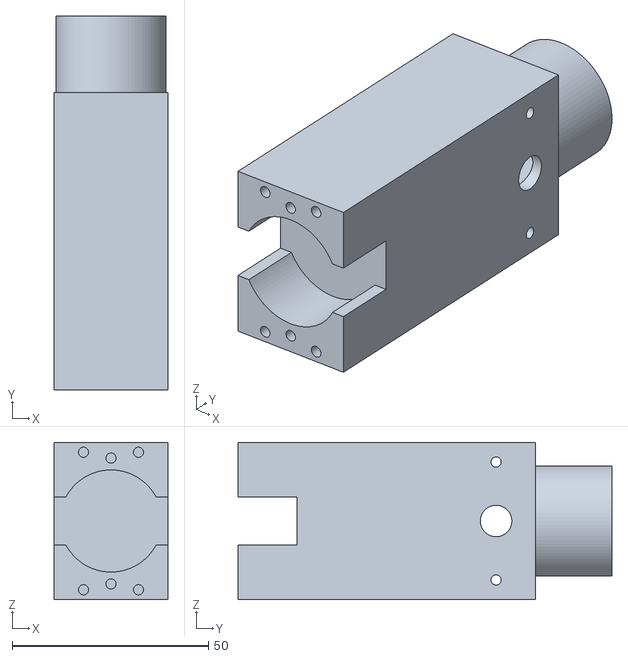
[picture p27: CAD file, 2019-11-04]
3D_printing/testtubeholder.stl
29.0 x 95.2 x 40.0

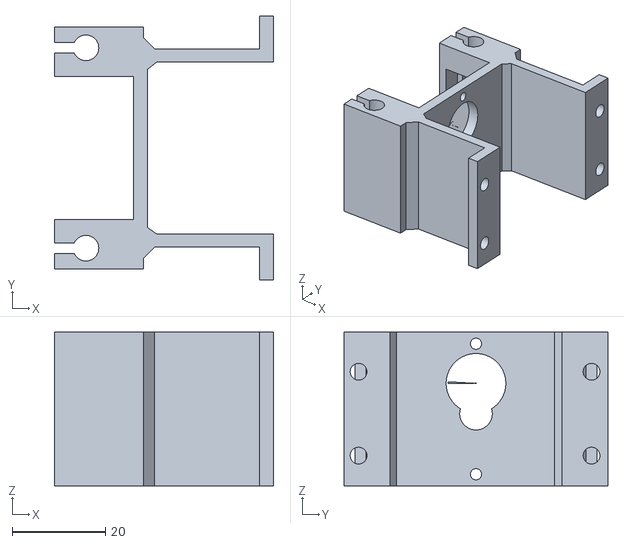
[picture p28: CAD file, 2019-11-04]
3D_printing/Valve.stl
47.0 x 56.6 x 33.0

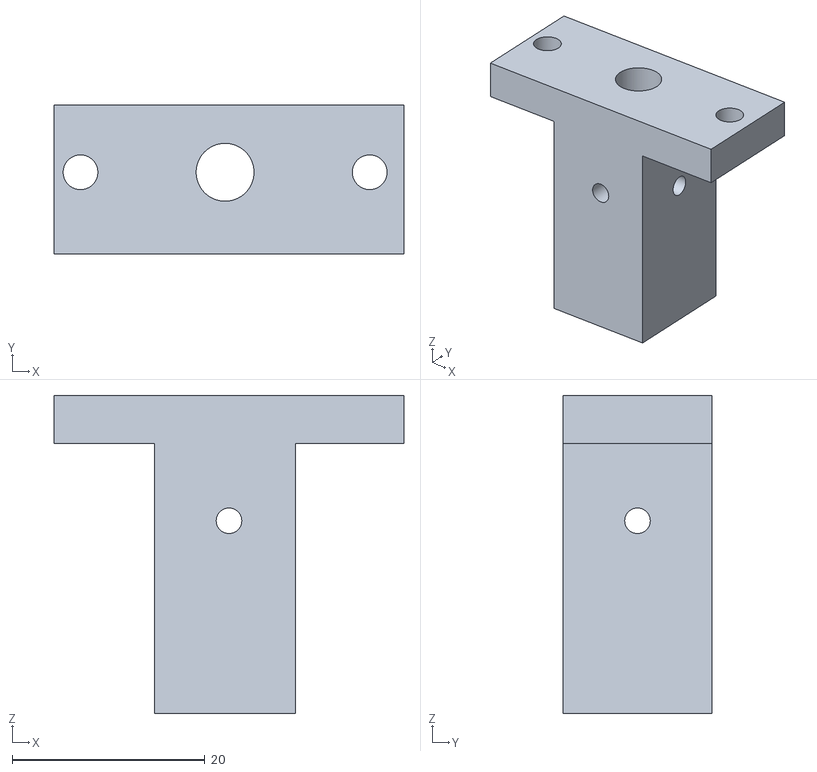
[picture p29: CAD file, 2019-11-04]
3D_printing/LaserHolder.stl
36.3 x 15.5 x 33.0

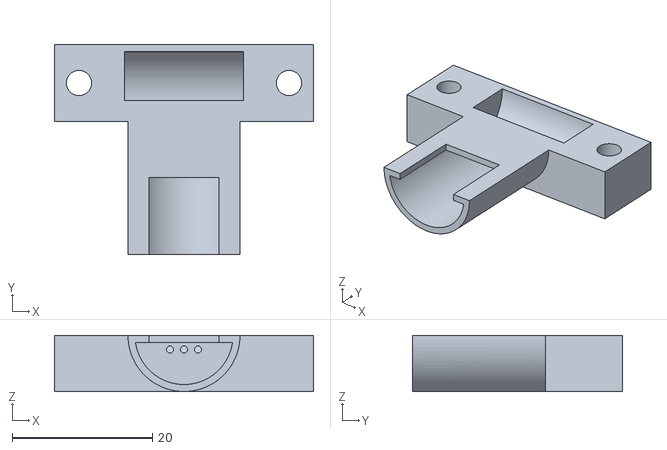
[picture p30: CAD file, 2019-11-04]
3D_printing/DiodeMount.stl
37.0 x 30.1 x 8.00

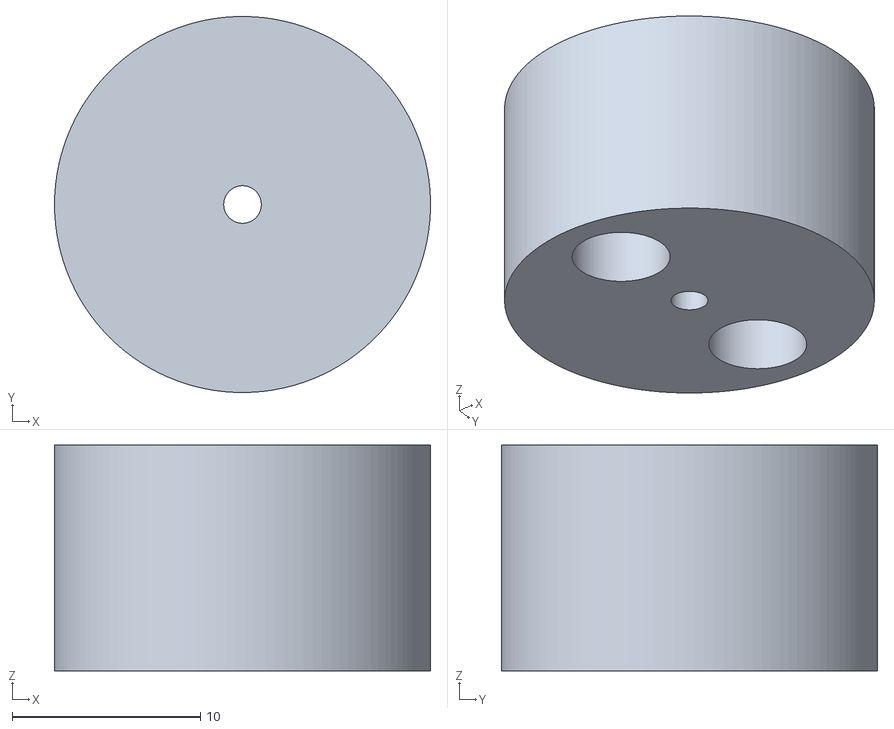
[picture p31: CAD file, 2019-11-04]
3D_printing/MagnetHolder.stl
20.0 x 20.0 x 12.0

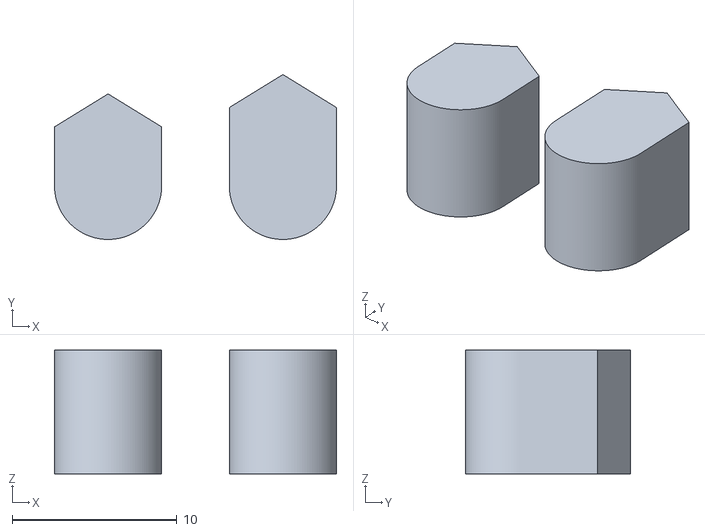
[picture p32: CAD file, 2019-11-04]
3D_printing/ValveWedge.stl
17.1 x 10.0 x 7.50

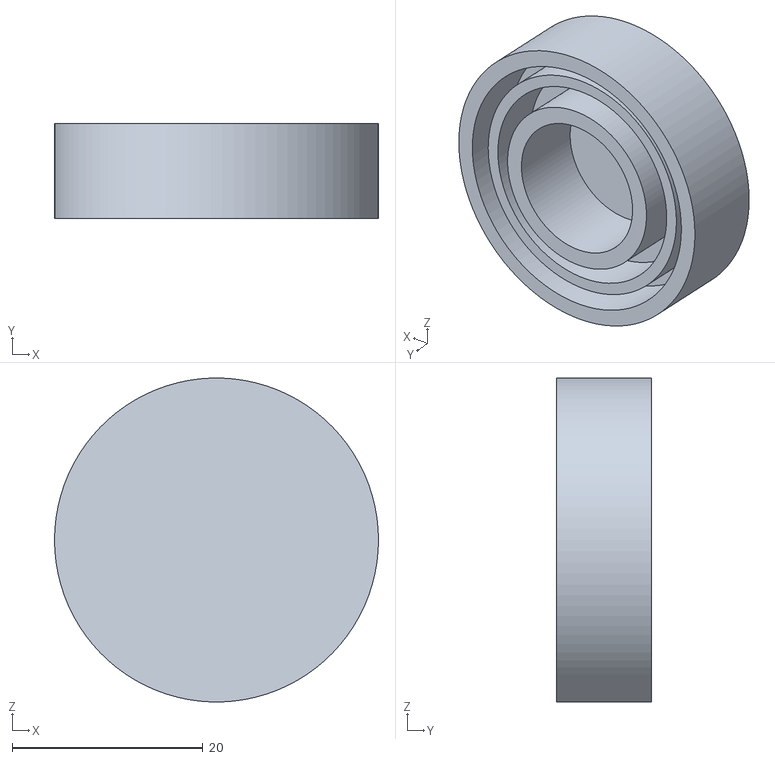
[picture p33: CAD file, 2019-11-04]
3D_printing/TopTubeGasket.stl
34.0 x 10.0 x 34.0

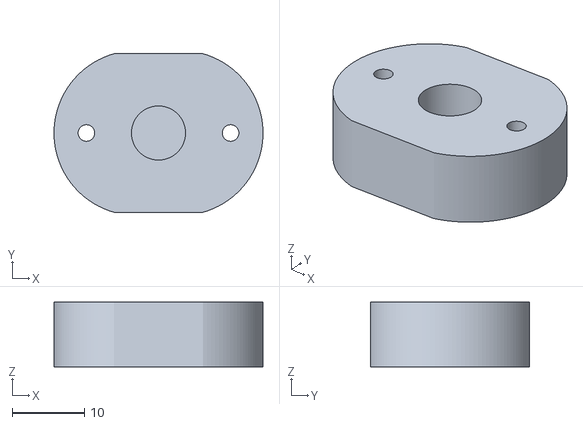
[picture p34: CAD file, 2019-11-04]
3D_printing/ValveLever.stl
29.0 x 22.0 x 9.00

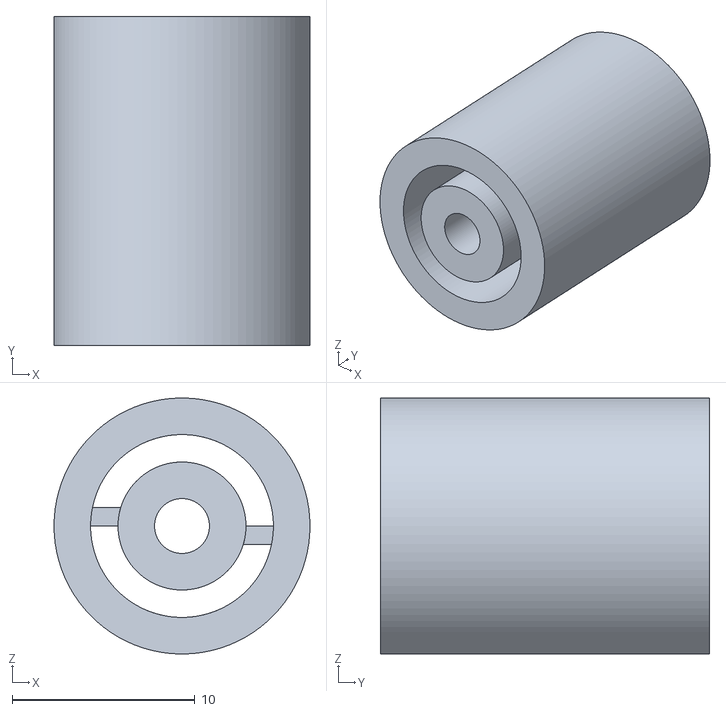
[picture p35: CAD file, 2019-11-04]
3D_printing/LaserGasket.stl
14.0 x 18.0 x 14.0

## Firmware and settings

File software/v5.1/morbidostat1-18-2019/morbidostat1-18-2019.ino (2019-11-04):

//Libraries
#include "Stepper.h"
#include "CommandHandler.h"
#include "MegunoLink.h"
#include "OneWire.h"
#include "DallasTemperature.h"
#include "Wire.h"
#include "Adafruit_PWMServoDriver.h"
#include "math.h"
//Defining Variables

//Agitation Variables
const int stepsPerRevolution = 200;  // change this to fit the number of steps per revolution for motors
int stepCount = 0;  // number of steps the motor has taken
int AgitationSpd = 2;//
int Agitation = 0;
int AgLight = 0;

// Tube choice variables
int tube1 = 0;
int tube2 = 0;
int tube3 = 0;
int tube4 = 0;
int tube5 = 0;
int tube6 = 0;

// Temperature Variables
int TempStatus = 0;
int TempLight = 0;
int setTemp = 37;
double temp = 20;
int heater = 2;    //heating pin
#define ONE_WIRE_BUS 3 // temperature sensor pin
unsigned long previousTempMillis = 0;
const long tempInterval = 10000;
float Min = 100;
float Max = 0;
//Temp Sensor Callup
OneWire oneWire(ONE_WIRE_BUS);
DallasTemperature sensors(&oneWire);

//Turbidity Reading Variables
int laserPin1 = 13; // Laser relay pin
int laserPin2 = 12;
int laserPin3 = 11;
int laserPin4 = 10;
int laserPin5 = 9;
int laserPin6 = 8;

//Calibration variables
float C1 = -0.57;
float C2 = -0.50;
float C3 = -0.55;
float C4 = -0.51;
float C5 = -0.48;
float C6 = -0.47;

float V01 = 3.11;
float V02 = 2.75;
float V03 = 3.01;
float V04 = 2.75;
float V05 = 2.66;
float V06 = 2.62;

int Laser1 = 4; // Laser Strength
int Laser2 = 4;
int Laser3 = 4;
int Laser4 = 4;
int Laser5 = 4;
int Laser6 = 4;
int ODStatus = 0; // Readings on or off
int ODStatusInt = 1; // Internal status to override OD measurements
int ODLight = 0;
float thrs1 = 0.4; // threshold to decide which pump is used
float thrs2 = 0.4;
float thrs3 = 0.4;
float thrs4 = 0.4;
float thrs5 = 0.4;
float thrs6 = 0.4;

float minthrs1 = 0.25; // minimum threshold to trigger dilution
float minthrs2 = 0.25;
float minthrs3 = 0.25;
float minthrs4 = 0.25;
float minthrs5 = 0.25;
float minthrs6 = 0.25;
unsigned long previousDilMillis = 0;
const long ReadInterval = 7000;  // interval between OD readings in milliseconds
double OD1 = 0.0; // Turbidity reading from tube 1
double OD2 = 0.0;
double OD3 = 0.0;
double OD4 = 0.0;
double OD5 = 0.0;
double OD6 = 0.0;

//Dilution Variables
int DilStatus = 0;
int AutDilLight = 0;
int AirPump = 52; // Air pump PIN check if correct in dilution function and beginning of loop!!!!!!!!!!!!!!!!!!!!!!!!!!!!!!!!!!!!!!!!!!!!!!
int AirDelay = 5; // time air pump is off after a dilution
int Air = 0;
unsigned long previousDilutionTime1 = 0;
unsigned long previousDilutionTime2 = 0;
unsigned long previousDilutionTime3 = 0;
unsigned long previousDilutionTime4 = 0;
unsigned long previousDilutionTime5 = 0;
unsigned long previousDilutionTime6 = 0;

double previousOD1 = 0.0; // Turbidity reading from tube 1
double previousOD2 = 0.0;
double previousOD3 = 0.0;
double previousOD4 = 0.0;
double previousOD5 = 0.0;
double previousOD6 = 0.0;

int CTime1 = 15; // (Cycle Time) Time between dilutions (mn)
int CTime2 = 15;
int CTime3 = 15;
int CTime4 = 15;
int CTime5 = 15;
int CTime6 = 15;

int DTime1 = 16; // Time pump runs during dilution (seconds)
int DTime2 = 16;
int DTime3 = 16;
int DTime4 = 16;
int DTime5 = 16;
int DTime6 = 16;

int PumpSpd = 100;

int LTTime = 60; //Time between dilutions if culture is below Lower threshold

int pump1 = 4;       //pump w/o antibiotics
int pump2 = 5;       //pump with antibiotics

int Tube1Pump = 1;  // for specifying which pump is on during dilutions in the messages
int Tube2Pump = 1;
int Tube3Pump = 1;
int Tube4Pump = 1;
int Tube5Pump = 1;
int Tube6Pump = 1;

// Digital pins for valves
int V1P1 = 30;
int V1P2 = 31;
int V2P1 = 32;
int V2P2 = 33;
int V3P1 = 34;
int V3P2 = 35;
int V4P1 = 36;
int V4P2 = 37;
int V5P1 = 38;
int V5P2 = 39;
int V6P1 = 40;
int V6P2 = 41;

// Array of valve pin numbers
int VPins[] = {
  V1P1, V1P2, V2P1, V2P2, V3P1, V3P2, V4P1, V4P2, V5P1, V5P2, V6P1, V6P2
};

// Cleaning
int Cleaning = 0;

// called this way, it uses the default address 0x40
Adafruit_PWMServoDriver pwm = Adafruit_PWMServoDriver();
// you can also call it with a different address you want
//Adafruit_PWMServoDriver pwm = Adafruit_PWMServoDriver(0x41);

//Plots and Messages in Megunolink
TimePlot MyPlot;
Message MyCSVMessage("Data"); //"Data" = the target message channel (remember to select this in megunolink)
Message PumpUsage("Pumps"); //What pump was used
InterfacePanel Panel("Control") ;  // Channel used in MLPUI Message processor in interface Panel
InterfacePanel Panel2("Settings");
InterfacePanel Panel3("Calibration");
//Megunolink Communications
CommandHandler<> SerialCommandHandler;

//Megunolink Functions

// Set length of time air pump is off during dilution
void SetAirDelay(CommandParameter &Parameters)
{
  AirDelay = Parameters.NextParameterAsInteger();
}
// Set laser strengths
void SetLaser1(CommandParameter &Parameters)
{
  Laser1 = Parameters.NextParameterAsInteger();
}

void SetLaser2(CommandParameter &Parameters)
{
  Laser2 = Parameters.NextParameterAsInteger();
}

void SetLaser3(CommandParameter &Parameters)
{
  Laser3 = Parameters.NextParameterAsInteger();
}

void SetLaser4(CommandParameter &Parameters)
{
  Laser4 = Parameters.NextParameterAsInteger();
}
void SetLaser5(CommandParameter &Parameters)
{
  Laser5 = Parameters.NextParameterAsInteger();
}
void SetLaser6(CommandParameter &Parameters)
{
  Laser6 = Parameters.NextParameterAsInteger();
}

//Set calibration functions
void SetC1(CommandParameter &Parameters)
{
  C1 = Parameters.NextParameterAsDouble();
}
void SetC2(CommandParameter &Parameters)
{
  C2 = Parameters.NextParameterAsDouble();
}
void SetC3(CommandParameter &Parameters)
{
  C3 = Parameters.NextParameterAsDouble();
}
void SetC4(CommandParameter &Parameters)
{
  C4 = Parameters.NextParameterAsDouble();
}
void SetC5(CommandParameter &Parameters)
{
  C5 = Parameters.NextParameterAsDouble();
}
void SetC6(CommandParameter &Parameters)
{
  C6 = Parameters.NextParameterAsDouble();
}
void SetV01(CommandParameter &Parameters)
{
  V01 = Parameters.NextParameterAsDouble();
}
void SetV02(CommandParameter &Parameters)
{
  V02 = Parameters.NextParameterAsDouble();
}
void SetV03(CommandParameter &Parameters)
{
  V03 = Parameters.NextParameterAsDouble();
}
void SetV04(CommandParameter &Parameters)
{
  V04 = Parameters.NextParameterAsDouble();
}
void SetV05(CommandParameter &Parameters)
{
  V05 = Parameters.NextParameterAsDouble();
}
void SetV06(CommandParameter &Parameters)
{
  V06 = Parameters.NextParameterAsDouble();
}



// Setting "controls" panel function
void SetODOn(CommandParameter &Parameters)
{
  ODStatus = 1;
  ODLight = 1;
  Panel.SetProgress("ODLight", ODLight);
}
void SetODOff(CommandParameter &Parameters)
{
  ODStatus = 0;
  ODLight = 0;
  Panel.SetProgress("ODLight", ODLight);
}
void SetColors(CommandParameter &Parameters)
{
  MyPlot.SetTitle("Turbidimeter");
  MyPlot.SetXlabel("Time");
  MyPlot.SetYlabel("OD");
  MyPlot.SetSeriesProperties("Tube1-P1", Plot::Magenta, Plot::Solid, 2, Plot::Star);
  MyPlot.SetSeriesProperties("Tube1-P2", Plot::Magenta, Plot::Solid, 2, Plot::Square);
  MyPlot.SetSeriesProperties("Tube2-P1", Plot::Green, Plot::Solid, 2, Plot::Star);
  MyPlot.SetSeriesProperties("Tube2-P2", Plot::Green, Plot::Solid, 2, Plot::Square);
  MyPlot.SetSeriesProperties("Tube3-P1", Plot::Blue, Plot::Solid, 2, Plot::Star);
  MyPlot.SetSeriesProperties("Tube3-P2", Plot::Blue, Plot::Solid, 2, Plot::Square);
  MyPlot.SetSeriesProperties("Tube4-P1", Plot::Red, Plot::Solid, 2, Plot::Star);
  MyPlot.SetSeriesProperties("Tube4-P2", Plot::Red, Plot::Solid, 2, Plot::Square);
  MyPlot.SetSeriesProperties("Tube5-P1", Plot::Cyan, Plot::Solid, 2, Plot::Star);
  MyPlot.SetSeriesProperties("Tube5-P2", Plot::Cyan, Plot::Solid, 2, Plot::Square);
  MyPlot.SetSeriesProperties("Tube6-P1", Plot::Black, Plot::Solid, 2, Plot::Star);
  MyPlot.SetSeriesProperties("Tube6-P2", Plot::Black, Plot::Solid, 2, Plot::Square);
}
void SetAutDilOn(CommandParameter &Parameters)
{
  DilStatus = 1;
  AutDilLight = 1;
  Panel.SetProgress("AutDilLight", AutDilLight);
}
void SetAutDilOff(CommandParameter &Parameters)
{
  DilStatus = 0;
  AutDilLight = 0;
  Panel.SetProgress("AutDilLight", AutDilLight);
}
void SetTempOn(CommandParameter &Parameters)
{
  TempStatus = 1;
  TempLight = 1;
  Panel.SetProgress("TempLight", TempLight);
}
void SetTempOff(CommandParameter &Parameters)
{
  TempStatus = 0;
  TempLight = 0;
  Panel.SetProgress("TempLight", TempLight);
}

void Cmd_SetTemp(CommandParameter &Parameters)
{
  setTemp = Parameters.NextParameterAsInteger();
}
void DoTempMin(CommandParameter &Parameters)
{
  Min = 100;
  Panel.SetNumber("MinTemp", Min);
}

void DoTempMax(CommandParameter &Parameters)
{
  Max = 0;
  Panel.SetNumber("MaxTemp", Max);
}

void SetTube1(CommandParameter &Parameters)
{

  tube1 = Parameters.NextParameterAsInteger();
}

void SetTube2(CommandParameter &Parameters)
{

  tube2 = Parameters.NextParameterAsInteger();
}

void SetTube3(CommandParameter &Parameters)
{

  tube3 = Parameters.NextParameterAsInteger();
}

void SetTube4(CommandParameter &Parameters)
{

  tube4 = Parameters.NextParameterAsInteger();
}

void SetTube5(CommandParameter &Parameters)
{

  tube5 = Parameters.NextParameterAsInteger();
}

void SetTube6(CommandParameter &Parameters)
{

  tube6 = Parameters.NextParameterAsInteger();
}
//Megunolink Functions for Settings
void SetThrs1(CommandParameter &Parameters)
{
  thrs1 = Parameters.NextParameterAsDouble();
  Serial.println(thrs1);
}

void SetThrs2(CommandParameter &Parameters)
{
  thrs2 = Parameters.NextParameterAsDouble();
  Serial.println(thrs2);
}

void SetThrs3(CommandParameter &Parameters)
{
  thrs3 = Parameters.NextParameterAsDouble();
  Serial.println(thrs3);
}

void SetThrs4(CommandParameter &Parameters)
{
  thrs4 = Parameters.NextParameterAsDouble();
  Serial.println(thrs4);
}

void SetThrs5(CommandParameter &Parameters)
{
  thrs5 = Parameters.NextParameterAsDouble();
  Serial.println(thrs5);
}

void SetThrs6(CommandParameter &Parameters)
{
  thrs6 = Parameters.NextParameterAsDouble();
  Serial.println(thrs6);
}
// Set miniumum thresholds
void SetLThrs1(CommandParameter &Parameters)
{
  minthrs1 = Parameters.NextParameterAsDouble();
  Serial.println(minthrs1);
}

void SetLThrs2(CommandParameter &Parameters)
{
  minthrs2 = Parameters.NextParameterAsDouble();
  Serial.println(minthrs2);
}

void SetLThrs3(CommandParameter &Parameters)
{
  minthrs3 = Parameters.NextParameterAsDouble();
  Serial.println(minthrs3);
}

void SetLThrs4(CommandParameter &Parameters)
{
  minthrs4 = Parameters.NextParameterAsDouble();
  Serial.println(minthrs4);
}

void SetLThrs5(CommandParameter &Parameters)
{
  minthrs5 = Parameters.NextParameterAsDouble();
  Serial.println(minthrs5);
}

void SetLThrs6(CommandParameter &Parameters)
{
  minthrs6 = Parameters.NextParameterAsDouble();
  Serial.println(minthrs6);
}
// Set Cycle Time Functions
void SetCTime1(CommandParameter &Parameters)
{
  CTime1 = Parameters.NextParameterAsInteger();
  Serial.println(CTime1);
}

void SetCTime2(CommandParameter &Parameters)
{
  CTime2 = Parameters.NextParameterAsInteger();
  Serial.println(CTime2);
}

void SetCTime3(CommandParameter &Parameters)
{
  CTime3 = Parameters.NextParameterAsInteger();
  Serial.println(CTime3);
}

void SetCTime4(CommandParameter &Parameters)
{
  CTime4 = Parameters.NextParameterAsInteger();
  Serial.println(CTime4);
}

void SetCTime5(CommandParameter &Parameters)
{
  CTime5 = Parameters.NextParameterAsInteger();
  Serial.println(CTime5);
}

void SetCTime6(CommandParameter &Parameters)
{
  CTime6 = Parameters.NextParameterAsInteger();
  Serial.println(CTime6);
}
// Set Dilution Time functions

void SetDTime1(CommandParameter &Parameters)
{
  DTime1 = Parameters.NextParameterAsInteger();
  Serial.println(DTime1);
}

void SetDTime2(CommandParameter &Parameters)
{
  DTime2 = Parameters.NextParameterAsInteger();
  Serial.println(DTime2);
}

void SetDTime3(CommandParameter &Parameters)
{
  DTime3 = Parameters.NextParameterAsInteger();
  Serial.println(DTime3);
}

void SetDTime4(CommandParameter &Parameters)
{
  DTime4 = Parameters.NextParameterAsInteger();
  Serial.println(DTime4);
}

void SetDTime5(CommandParameter &Parameters)
{
  DTime5 = Parameters.NextParameterAsInteger();
  Serial.println(DTime5);
}

void SetDTime6(CommandParameter &Parameters)
{
  DTime6 = Parameters.NextParameterAsInteger();
  Serial.println(DTime6);
}

//Set Pump Spd
void SetPumpSpd(CommandParameter &Parameters)
{
  PumpSpd = Parameters.NextParameterAsInteger();
  Serial.println(PumpSpd);
}

void SetLTTime(CommandParameter &Parameters)
{
  LTTime = Parameters.NextParameterAsInteger();
  Serial.println(LTTime);
}
// Megunolink Functions for Manual Overrides

void SetAir(CommandParameter &Parameters)    //turn on/off air pump
{
  //Serial.println("Air");
  Air = Parameters.NextParameterAsInteger();
  if (Air == 1) {
    digitalWrite(AirPump, HIGH);
  }
  else {
    digitalWrite(AirPump, LOW);
  }
}

void SetPump1(CommandParameter &Parameters)
{
  Serial.println("Pump1");
  int Pump01 = Parameters.NextParameterAsInteger();
  if (Pump01 == 1) {
    analogWrite(pump1, (PumpSpd * 255 / 100));
  }
  else {
    analogWrite(pump1, LOW);
  }
}
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
void loop() {
  SerialCommandHandler.Process();

  // Temperature Control using Dallas Temperature Library
  unsigned long currentTempMillis = millis();
  if (currentTempMillis - previousTempMillis >= tempInterval)
  {
    previousTempMillis = currentTempMillis;     // save the last time you checked Temperature
    if (TempStatus == 1)
    {
      Serial.println("Temperature");
      sensors.requestTemperatures(); // Send the command to get temperatures
      temp = sensors.getTempCByIndex(0);
      if (temp < setTemp)
      {
        digitalWrite(heater, HIGH);
      }
      else
      {
        digitalWrite(heater, LOW);
      }
    }
    else
    {
      digitalWrite(heater, LOW);
    }
    sensors.requestTemperatures();
    float temp = sensors.getTempCByIndex(0);
    if (temp >= Max)
    {
      Max = temp;
    }
    if (temp <= Min)
    {
      Min = temp;
    }
    Panel.SetNumber("MinTemp", Min);
    Panel.SetNumber("MaxTemp", Max);
    Panel.SetNumber("CurrentTemp", temp);
  }//Time to Read temperature

  //Turbidity Readings

  // if it is time to read

  unsigned long currentDilMillis = millis();
  if (currentDilMillis - previousDilMillis >= ReadInterval)
  {
    previousDilMillis = currentDilMillis;
    // if turbity readings button is on -- read
    if (ODStatus == 1 & ODStatusInt == 1)
    {
      analogWrite(laserPin1, Laser1); // turn on lasers
      analogWrite(laserPin2, Laser2);
      analogWrite(laserPin3, Laser3);
      analogWrite(laserPin4, Laser4);
      analogWrite(laserPin5, Laser5);
      analogWrite(laserPin6, Laser6);
      delay(100);

      double Od[] = {0.0, 0.0, 0.0, 0.0, 0.0, 0.0};

      int pdarray[] = {A0, A3, A6, A9, A12, A15};

      for (int k = 0; k < 300; k = k + 1) // iterate through photodiodes
      {
        for (int pd = 0; pd <= 5; pd = pd + 1)
        {
          int P = analogRead(pdarray[pd]);
          Od[pd] = Od[pd] + P;
        }
      }


      OD1 = C1 * log10(Od[0]) + V01;
      OD2 = C2 * log10(Od[1]) + V02;
      OD3 = C3 * log10(Od[2]) + V03;
      OD4 = C4 * log10(Od[3]) + V04;
      OD5 = C5 * log10(Od[4]) + V05;
      OD6 = C6 * log10(Od[5]) + V06;

      analogWrite(laserPin1, 0); // turn off lasers
      analogWrite(laserPin2, 0);
      analogWrite(laserPin3, 0);
      analogWrite(laserPin4, 0);
      analogWrite(laserPin5, 0);
      analogWrite(laserPin6, 0);

      // send to graph and to message if tube # is checked in settings
      if (tube1 == 1)
      {

        MyCSVMessage.Begin();  //Message for tube 1
        Serial.print("Tube1");
        Serial.print(",");
        Serial.print(OD1);
        Serial.print(",");
        if (Tube1Pump == 1)
        {
          Serial.print("Pump1");
          MyCSVMessage.End();
          MyPlot.SendData("Tube1-P1", (OD1));
        }
        else
        {
          Serial.print("Pump2");
          MyCSVMessage.End();
          MyPlot.SendData("Tube1-P2", (OD1));
        }

      }
      if (tube2 == 1)
      {
        MyCSVMessage.Begin();  //Message for tube 2
        Serial.print("Tube2");
        Serial.print(",");
        Serial.print(OD2);
        Serial.print(",");
        if (Tube2Pump == 1)
        {
          Serial.print("Pump1");
          MyCSVMessage.End();
          MyPlot.SendData("Tube2-P1", (OD2));
        }
        else
        {
          Serial.print("Pump2");
          MyCSVMessage.End();
          MyPlot.SendData("Tube2-P2", (OD2));
        }

      }
      if (tube3 == 1)
      {
        MyCSVMessage.Begin();  //Message for tube 3
        Serial.print("Tube3");
        Serial.print(",");
        Serial.print(OD3);
        Serial.print(",");
        if (Tube3Pump == 1)
        {
          Serial.print("Pump1");
          MyCSVMessage.End();
          MyPlot.SendData("Tube3-P1", (OD3));
        }
        else
        {
          Serial.print("Pump2");
          MyCSVMessage.End();
          MyPlot.SendData("Tube3-P2", (OD3));
        }

      }
      if (tube4 == 1)
      {
        MyCSVMessage.Begin();  //Message for tube 4
        Serial.print("Tube4");
        Serial.print(",");
        Serial.print(OD4);
        Serial.print(",");
        if (Tube4Pump == 1)
        {
          Serial.print("Pump1");
          MyCSVMessage.End();
          MyPlot.SendData("Tube4-P1", (OD4));
        }
        else
        {
          Serial.print("Pump2");
          MyCSVMessage.End();
          MyPlot.SendData("Tube4-P2", (OD4));
        }

      }
      if (tube5 == 1)
      {

        MyCSVMessage.Begin();  //Message for tube 5
        Serial.print("Tube5");
        Serial.print(",");
        Serial.print(OD5);
        Serial.print(",");
        if (Tube5Pump == 1)
        {
          Serial.print("Pump1");
          MyCSVMessage.End();
          MyPlot.SendData("Tube5-P1", (OD5));
        }
        else
        {
          Serial.print("Pump2");
          MyCSVMessage.End();
          MyPlot.SendData("Tube5-P2", (OD5));
        }

      }
      if (tube6 == 1)
      {

        MyCSVMessage.Begin();  //Message for tube 6
        Serial.print("Tube6");
        Serial.print(",");
        Serial.print(OD6);
        Serial.print(",");
        if (Tube6Pump == 1)
        {
          Serial.print("Pump1");
          MyCSVMessage.End();
          MyPlot.SendData("Tube6-P1", (OD6));
        }
        else
        {
          Serial.print("Pump2");
          MyCSVMessage.End();
          MyPlot.SendData("Tube6-P2", (OD6));
        }
      }

      // Check to see if Automatic Dilution is ON
      if (DilStatus == 1)
      {
        unsigned long currentDilutionTime1 = millis();
        unsigned long currentDilutionTime2 = millis();
        unsigned long currentDilutionTime3 = millis();
        unsigned long currentDilutionTime4 = millis();
        unsigned long currentDilutionTime5 = millis();
        unsigned long currentDilutionTime6 = millis();
        
        // If time to Dilute Tube1
        if (currentDilutionTime1 - previousDilutionTime1 >= LTTime * 60000  && Cleaning == 0 && tube1 == 1 && OD1 <= minthrs1)
        {
          previousDilutionTime1 = currentDilutionTime1;
          // Serial.println("AutDil");
          Dilution(PumpSpd, DTime1, pump1, V1P1, AirDelay); //Run dilution
          Tube1Pump = 1;
          PumpUsage.Begin();
          Serial.print("Tube1 - Pump1");
          PumpUsage.End();
          previousOD1 = OD1;
        }
        else if (currentDilutionTime1 - previousDilutionTime1 >= CTime1 * 60000  && Cleaning == 0 && tube1 == 1 && OD1 >= minthrs1)
        {

          previousDilutionTime1 = currentDilutionTime1;   // save Dilution Time
          // Serial.println("AutDil");
          if (OD1 >= thrs1 && OD1 >= previousOD1)
          {
            Dilution(PumpSpd, DTime1, pump2, V1P2, AirDelay); //Run dilution
            Tube1Pump = 2;
            PumpUsage.Begin();
            Serial.print("Tube1 - Pump2");
            PumpUsage.End();
          }
          else
          {
            Dilution(PumpSpd, DTime1, pump1, V1P1, AirDelay); //Run dilution
            Tube1Pump = 1;
            PumpUsage.Begin();
            Serial.print("Tube1 - Pump1");
            PumpUsage.End();
          }
          previousOD1 = OD1;


        }

        if (currentDilutionTime1 - previousDilutionTime1 >= CTime1 * 60000  && Cleaning == 1 && tube1 == 1)
        {
          Dilution(PumpSpd, DTime1, pump1, V1P1, AirDelay); //Run Cleaning w/ pump1
        }
        if (currentDilutionTime1 - previousDilutionTime1 >= CTime1 * 60000  && Cleaning == 2 && tube1 == 1)
        {
          Dilution(PumpSpd, DTime1, pump2, V1P2, AirDelay); //Run Cleaning w/ pump2
        }

        if (currentDilutionTime1 - previousDilutionTime1 >= 15000  && Cleaning == 3 && tube1 == 1)    // check OD every 15 sec in turbidostat mode
        {
          if( OD1 >= thrs1 ){
            Dilution(PumpSpd, DTime1, pump1, V1P1, AirDelay); //Run dilution with pump 1
          }
          previousDilutionTime1 = currentDilutionTime1;
          PumpUsage.Begin();
          Serial.print("Tube1 Dilution");
          PumpUsage.End();
        }

        // If time to Dilute Tube2
        if (currentDilutionTime2 - previousDilutionTime2 >= LTTime * 60000  && Cleaning == 0 && tube2 == 1 && OD2 <= minthrs2)
        {
          previousDilutionTime2 = currentDilutionTime2;
          // Serial.println("AutDil");
          Dilution(PumpSpd, DTime2, pump1, V2P1, AirDelay); //Run dilution
          Tube2Pump = 1;
          PumpUsage.Begin();
          Serial.print("Tube2 - Pump1");
          PumpUsage.End();
          previousOD2 = OD2;
        }
        else if (currentDilutionTime2 - previousDilutionTime2 >= CTime2 * 60000 && Cleaning == 0 && tube2 == 1 && OD2 >= minthrs2)
        {
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

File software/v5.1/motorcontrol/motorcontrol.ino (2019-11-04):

 //Libraries
#include "Stepper.h"
#include "CommandHandler.h"
#include "MegunoLink.h"
#include "OneWire.h"
#include "DallasTemperature.h"
#include "Wire.h"
#include "Adafruit_PWMServoDriver.h"

//Agitation Variables
const int stepsPerRevolution = 200;  // change this to fit the number of steps per revolution for motors
int stepCount = 0;  // number of steps the motor has taken
int AgitationSpd = 2;// 
int Agitation = 0;
int AgLight = 0;
int stepperPin =7;
// initialize the stepper library for agitation  :
//Agitation pins are from 22 to 45
Stepper Stepper1(stepsPerRevolution, 22, 24, 26, 28);
Stepper Stepper2(stepsPerRevolution, 23, 25, 27, 29);
Stepper Stepper3(stepsPerRevolution, 30, 32, 34, 36);
Stepper Stepper4(stepsPerRevolution, 31, 33, 35, 37);
Stepper Stepper5(stepsPerRevolution, 38, 40, 42, 44);
Stepper Stepper6(stepsPerRevolution, 46, 48, 50, 52);

InterfacePanel Panel("Control") ;  // Channel used in MLPUI Message processor in interface Panel
InterfacePanel Panel2("Settings");
//Megunolink Communications
CommandHandler<> SerialCommandHandler;

//Megunolink Functions
void SetAgOn(CommandParameter &Parameters)           
{
  Agitation= 1;
  AgLight =1;
  Panel.SetProgress("AgLight",AgLight);
}
void SetAgOff(CommandParameter &Parameters)           
{
  Agitation= 0;
  AgLight =0;
  Panel.SetProgress("AgLight",AgLight);
}

void SetAgSpd(CommandParameter &Parameters)           
{
  AgitationSpd=Parameters.NextParameterAsInteger();
}

void DoUnknown()
{
  Serial.println("I don't understand!");                        
}

void setup() {
  // put your setup code here, to run once:
  // Set baud rate
  Serial.begin(9600);
  //Turn Panel Light Off
  Panel.SetProgress("AgLight",AgLight);

   SerialCommandHandler.AddCommand(F("AgOn"), SetAgOn);
 SerialCommandHandler.AddCommand(F("AgOff"), SetAgOff);
 SerialCommandHandler.AddCommand(F("SetSpd"), SetAgSpd);
 SerialCommandHandler.SetDefaultHandler(DoUnknown);
}

void loop() {
  // put your main code here, to run repeatedly:
SerialCommandHandler.Process();
digitalWrite(stepperPin, LOW);
// Agitation Control
  if (Agitation == 1)  {
//    Serial.println("SetupOver");
    // step a revolution:
 //   Serial.println("Agitation");
    Stepper1.step(1);
    Stepper2.step(1);
    Stepper3.step(1);
    Stepper4.step(1);
    Stepper5.step(1);
    Stepper6.step(1);
    delayMicroseconds(1500+1000*AgitationSpd);
  //  Serial.println("Agitation");
      
  }
  else 
  {
    SerialCommandHandler.Process();
  }
}

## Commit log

2019-11-06 Added SOP
    [DiodeMount.stl, LaserHolder.stl, MagnetHolder.stl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]
2019-11-06 Added components spreadsheet
    [components.xlsx]
2022-03-02 Update Calibration SOP
2022-03-04 Updated calibration manual. Set default calibration parameters.
2022-03-07 Added goal of calibration
